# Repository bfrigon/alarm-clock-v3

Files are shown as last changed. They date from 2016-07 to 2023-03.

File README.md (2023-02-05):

alarm-clock (V3)
================

Project page [here][link-project]

Specs
-----

- Arduino based design using the ATMEGA2560 MCU.
- Plays MP3/WAV files from a SD card.
- WiFi connectivity (802.11 b/g/n)
- Automatic clock synchronization using NTP
- Send alarm state to Home Assistant via MQTT
- Large RGB seven segment display
- 16x2 character LCD display
- Night lamp
- Touch keypad
- 24h battery backup

---------------------------------------------------

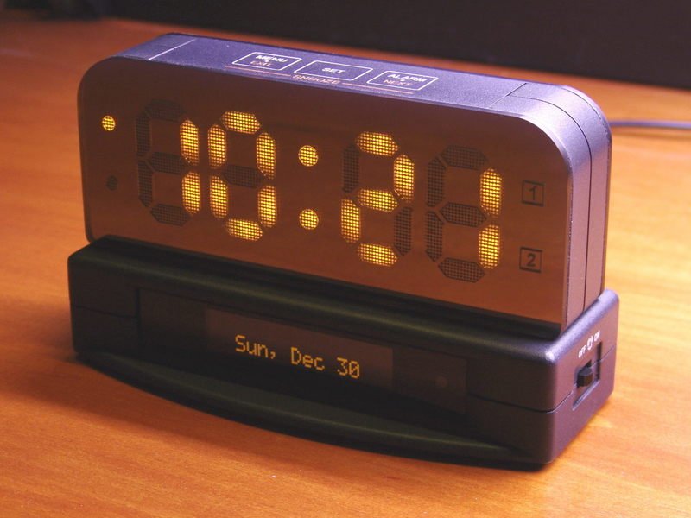
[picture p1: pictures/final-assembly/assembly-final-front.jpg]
Front view

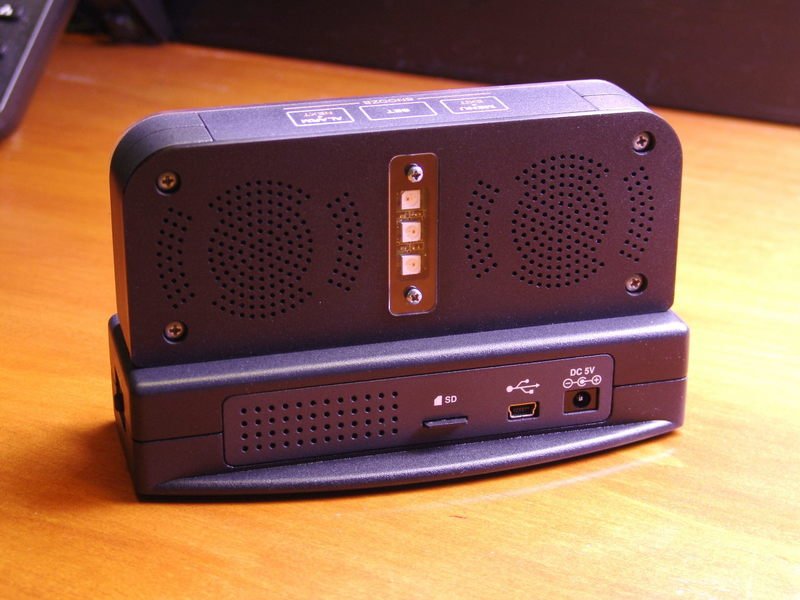
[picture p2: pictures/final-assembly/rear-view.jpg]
Rear view


Home Assistant
--------------
The clock can send the alarm switch state and next alarm timestamp to Home Assistant via MQTT. This allows to run home automations based on the alarm time. It also sends other data such as WiFi signal strength, power state, battery voltage and remaining capacity.

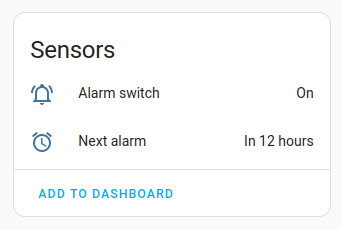
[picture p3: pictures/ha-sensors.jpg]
Home Assistant sensors


[link-project]:https://www.frigon.info/posts/projects/alarm-clock-v3/

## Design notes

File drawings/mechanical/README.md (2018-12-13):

Index
-----

Document ID   | Part #            | Description
--------------|-------------------|-------------------------------------------------
CLKV3-DWG-01  | CLKV3-PC-01       | Display - RGB digit PCB
CLKV3-DWG-02  | CLKV3-ML-01       | Display - Frame - Front
CLKV3-DWG-03  | CLKV3-ML-03       | Display - Front cover
CLKV3-DWG-04  | CLKV3-ML-09       | Display - Frame - Back
CLKV3-DWG-05  | CLKV3-ML-02       | Display - Back cover
CLKV3-DWG-06  | CLKV3-PC-02       | Display - RGB dots PCB
CLKV3-DWG-07  | CLKV3-PC-03       | Touch keypad PCB
CLKV3-DWG-08  | CLKV3-ML-04       | Touch keypad overlay
CLKV3-DWG-09  | CLKV3-PC-08       | RGB lamp PCB
CLKV3-DWG-10  | CLKV3-ML-05       | Enclosure - Lower section
CLKV3-DWG-11  | CLKV3-ML-06       | Enclosure - Upper section
CLKV3-DWG-12  | CLKV3-PC-04       | Front panel PCB
CLKV3-DWG-13  | CLKV3-ML-10       | Enclosure - Back panel
CLKV3-DWG-14  | CLKV3-PC-05       | Motherboard PCB
CLKV3-DWG-15  | CLKV3-PC-06       | Daughterboard PCB
CLKV3-DWG-16  | CLKV3-PC-07       | PSU PCB
CLKV3-DWG-17  | CLKV3-PC-09       | Alarm switch PCB
CLKV3-DWG-18  | CLKV3-ML-07       | RTC Battery door
CLKV3-DWG-19  | CLKV3-ML-08       | RGB lamp window - Frame
CLKV3-DWG-20  | CLKV3-ML-09       | RGB lamp window - Cover
CLKV3-DWG-21  | CLKV3-ML-11       | Front panel window
CLKV3-DWG-22  | CLKV3-ML-12       | Battery holder
CLKV3-DWG-30  | CLKV3-AS-01       | ASSY - Display frame - Front
CLKV3-DWG-31  | CLKV3-AS-02       | ASSY - Display frame - Back
CLKV3-DWG-32  | CLKV3-AS-03       | ASSY - Display
CLKV3-DWG-33  | CLKV3-AS-04       | ASSY - Motherboard PCB
CLKV3-DWG-34  | CLKV3-AS-05       | ASSY - Touch keypad
CLKV3-DWG-35  | CLKV3             | Final assembly
CLKV3-DWG-50  | CLKV3-JG-01       | Jig - dev.
CLKV3-DWG-51  | CLKV3-JG-02       | Motherboard assembly jig

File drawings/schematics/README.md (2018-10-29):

Index
-----

Doc ID        | Part #            | Description
--------------|-------------------|-------------------------------------------------
CLKV3-SCH-01  | CLKV3-PC-01       | Display - RGB seven seg. digit
CLKV3-SCH-02  | CLKV3-PC-02       | Display - RGB dots
CLKV3-SCH-03  | CLKV3-PC-03       | Touch keypad
CLKV3-SCH-04  | CLKV3-PC-04       | Front panel
CLKV3-SCH-05  | CLKV3-PC-05       | Motherboard
CLKV3-SCH-06  | CLKV3-PC-06       | Daughterboard
CLKV3-SCH-07  | CLKV3-PC-07       | PSU PCB
CLKV3-SCH-08  | CLKV3-PC-08       | RGB Lamp
CLKV3-SCH-09  | CLKV3-PC-09       | Alarm Swtich PCB

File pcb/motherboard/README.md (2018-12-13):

### Bill of material ###

```
Date    : 2018-10-29
Doc. ID : CLKV3-SCH-05
Project : Alarm Clock (V3)
Title   : Motherboard

Part #  : CLKV3-PC-05
REV.    : B

Components : 76
```

------------------------------------------------------------------------------------------------------------------------

| Qty | Ref. | Description | Value | Part # | Footprint |
|-----|---|---|---|---|---|
| 1 | J5 | Micro SD card connector | Micro_SD | 475710001 | conn-io:MOLEX-MICROSD-475710001 |
| 1 | J10 | Header - Dual Row - 6 Pos | PSU | BCS-103-L-D-TE | conn-header:HDR-M-2x03 |
| 1 | J6 | Header - Single Row - 4 Pos | PSU-SIG | BCS-104-L-S-TE | conn-header:HDR-M-1x04 |
| 2 | J4, J7 | Header - Dual Row - 6 Pos | ICSP | CES-103-01-T-D | conn-header:HDR-M-2x03 |
| 1 | J12 | Header - Single Row - 2 Pos | DB-C | DW-02-07-T-S-200 | conn-header:HDR-M-1x02 |
| 1 | J3 | Header - Single Row - 4 Pos | DB-B | DW-04-07-TM-S-200  | conn-header:HDR-M-1x04 |
| 1 | J9 | Header - Dual Row - 16 Pos | DB-A | DW-08-07-T-D-200 | conn-header:HDR-M-2x08 |
| 1 | J1 | DC Barrel Jack | - | PJ1-021-SMT-TR | conn-power:CUI-P1J-021-SMT |
| 1 | J2 | USB Connector - Type B | USB-MINI-B | UX60SC-MB-5ST | conn-io:USB-MB_UX60SC-MB-5ST |
| 1 | Q1 | 40V NPN small signal transistor | MMST3904 | - | smt-sot:SOT23 |
| 1 | U6 | 600mA CMOS LDO Regulator with enable | - | AP2112K-3.3 | smt-sot:SOT23-5 |
| 1 | U3 | 8-bit Atmel Microcontroller | - | ATMEGA16U2-AU | smt-qfp:QFP-7-32 |
| 1 | U1 | 8-bit Atmel Microcontroller | - | ATMEGA2560-16AU | smt-qfp:QFP-14-100 |
| 1 | U4 | IEEE 802.11 b/g/n IoT Module | - | ATWINC1500-MR210PB | misc:ATWINC1500-MR |
| 2 | U5, U7 | Hex Buffer non-inverting | - | CD74HC4050PWR | smt-sop:TSSOP16 |
| 1 | U2 | I2C Real-Time Clock | - | DS3231MZ | smt-soic:SOIC8 |
| 8 | R10, R12-R18 | Resistor | 100k | - | smt:R-0603 |
| 12  | C3, C5-C6, C9-C11, C14, C22-C26 | Capacitor | 100nF | - | smt:C-0603 |
| 9 | R1-R2, R5-R6, R9, R11, R20-R22  | Resistor | 10k | - | smt:R-0603 |
| 1 | C15 | Capacitor | 10nF | - | smt:C-0603 |
| 4 | C16-C18, C21 | Capacitor | 10uF | - | smt:C-0805 |
| 3 | R19, R23-R24 | Resistor | 1k | - | smt:R-0603 |
| 2 | R7-R8 | Resistor | 1M | - | smt:R-0603 |
| 1 | C13 | Capacitor | 1uF | - | smt:C-0603 |
| 3 | C4, C19-C20 | Capacitor | 1uF | - | smt:C-0805 |
| 4 | C1-C2, C7-C8 | Capacitor | 20pF | - | smt:C-0603 |
| 1 | C12 | Capacitor | 22pF | - | smt:C-0603 |
| 2 | R3-R4 | Resistor | 22 | - | smt:R-0603 |
| 1 | F1 | Resistor | 500mA | - | smt:R-1206 |
| 1 | DA1 | TVS Diode Array | SR05 | - | smt-sot:SOT-143 |
| 2 | D1-D2 | Diode | - | CD1206-S01575 | smt:D-1206 |
| 2 | Y1-Y2 | Crystal | 16.00 MHz  | ECS-160-20-3X-TR | crystals:smt-CSM-3X-7x4mm |
| 1 | B1 | Battery - 1 cell | CR1220 | S8411-45R | conn-power:S8411-45R |
| 1 | SW1 | Momentary SPST switch | RESET | B3F-1000 | switches:B3F-10XX |

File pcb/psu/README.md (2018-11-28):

### Bill of material ###

```
Date    : None
Doc. ID : CLKV3-SCH-07
Project : Alarm Clock (V3)
Title   : Power Supply

Part #  : CLKV3-PC-07
REV.    : A

Components : 40
```

------------------------------------------------------------------------------------------------------------------------

| Qty | Ref. | Description | Value | Part # | Footprint |
|-----|---|---|---|---|---|
| 1 | J3 | Header - Single Row - 2 Pos | BATTERY  | S2B-PH-K-S | conn-jst:S2B-PH-K |
| 1 | J1 | Header - Dual Row - 6 Pos | VIN | TSW-103-07-F-D | conn-header:HDR-M-2x03  |
| 1 | J2 | Header - Single Row - 4 Pos | SIGNAL | TSW-104-07-F-S | conn-header:HDR-M-1x04  |
| 2 | Q1-Q2 | 40V NPN small signal transistor | MMST3904 | - | smt-sot:SOT23 |
| 1 | U2 | Li-Ion Battery charger and Power-Path management | - | BQ24075 | smt-qfn:QFN16-EP-3x3 |
| 1 | U1 | System-side Impedance Track Fuel Gauge | - | BQ27441-G1 | smt-son:PDSO-N12 |
| 1 | U3 | 2V to 16V Buck-Boost converter | - | TPS630701 | smt-qfn:VQFN15N |
| 1 | R2 | Resistor | 0.01 1%  | - | smt:R-1206 |
| 1 | R10 | Resistor | 0 | - | smt:R-0603 |
| 1 | R9 | Resistor | 1.1k | - | smt:R-0603 |
| 5 | R3-R6, R12 | Resistor | 100k | - | smt:R-0603 |
| 1 | C4 | Capacitor | 100nF | - | smt:C-0603 |
| 6 | R1, R11, R13-R16 | Resistor | 10k | - | smt:R-0603 |
| 2 | C3, C5 | Capacitor | 10uF | - | smt:C-0603 |
| 5 | C1-C2, C11-C13 | Capacitor | 10uF | - | smt:C-0805 |
| 1 | C10 | Capacitor | 1uF | - | smt:C-0603 |
| 3 | C6-C8 | Capacitor | 22uF | - | smt:C-0805 |
| 1 | C9 | Capacitor | 470nF | - | smt:C-0603 |
| 1 | R8 | Resistor | 5.6k | - | smt:R-0603 |
| 1 | R17 | Resistor | 680 | - | smt:R-0603 |
| 1 | R7 | Resistor | 787k | - | smt:R-0603 |
| 1 | D1 | Led | RED | 150080RS75000 | smt:LED-0805 |
| 1 | L1 | Inductor | 1.5uH | SPM5030T-1R5M-HZ | smt-inductor:SPM5030-HZ |

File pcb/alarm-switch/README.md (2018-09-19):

### Bill of material ###

```
Date    : 2018-08-14
Doc. ID : CLKV3-SCH-09
Project : Alarm Clock V3
Title   : Alarm Switch Pcb

Part #  : CLKV3-PC-09
REV.    : A

Components : 1
```

------------------------------------------------------------------------------------------------------------------------

| Qty | Ref. | Description | Value | Part # | Footprint |
|-----|---|---|---|---|---|
| 1 | SW1  | Momentary SPST switch | L102011ML04Q | - | switches:CK_L102XXXML04 |

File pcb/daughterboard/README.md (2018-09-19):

### Bill of material ###

```
Date    : 2018-09-19
Doc. ID : CLKV3-SCH-06
Project : Alarm Clock (V3)
Title   : Daughterboard

Part #  : CLKV3-PC-06
REV.    : A

Components : 70
```

------------------------------------------------------------------------------------------------------------------------

| Qty | Ref. | Description | Value | Part # | Footprint |
|-----|---|---|---|---|---|
| 1 | J7 | Header - Single Row - 2 Pos | ALARM SW | DF3A-2P-2DSA | conn-header:DF3A-2P-2DSA  |
| 1 | J1 | Header - Single Row - 3 Pos | LAMP | DF3A-3P-2DSA | conn-header:DF3A-3P-2DSA  |
| 1 | J3 | Header - Single Row - 4 Pos | SPKR | DF3A-4P-2DSA | conn-header:DF3A-4P-2DSA  |
| 1 | J2 | Header - Single Row - 8 Pos | DISPLAY | DF3A-8P-2DSA | conn-header:DF3A-8P-2DSA  |
| 1 | U2 | Single inverter | - | 74AHC1G04SE-7 | smt-sot:SOT-353 |
| 1 | U3 | Dual 150mA LDO Regulator | - | AP7312-1833W6 | smt-sot:SOT23-6 |
| 1 | Q1 | Single P-Channel MOSFET 20V 10A | NTF6P02 | NTF6P02T3G | smt-sot:SOT-223 |
| 1 | U5 | Dual non-inverting buffer | - | SN74LVC2G34DBV | smt-sot:SOT23-6 |
| 1 | U4 | 2.8W/Ch Stereo Class-D Audio Amplifier | - | TPA2016D2 | smt-qfn:QFN20-EP-4x4 |
| 1 | U1 | MP3/AAC/MIDI Audio Codec | - | VS1053B | smt-qfp:QFP-7-48 |
| 10  | R4, R6, R12-R19 | Resistor | 100k | - | smt:R-0603 |
| 14  | C1-C10, C26-C27, C29-C30 | Capacitor | 100nF | - | smt:C-0603 |
| 3 | R2, R7, R11 | Resistor | 10k | - | smt:R-0603 |
| 2 | C18-C19 | Capacitor | 10nF | - | smt:C-0603 |
| 1 | R8 | Resistor | 10 | - | smt:R-0603 |
| 3 | C11, C14, C16 | Electrolytic capacitor | 10uF 6V3 | - | smt:CPL-0805 |
| 3 | C24-C25, C28 | Capacitor | 10uF | - | smt:C-0805 |
| 1 | R5 | Resistor | 1M | - | smt:R-0603 |
| 4 | C31-C34 | Capacitor | 1nF | - | smt:C-0603 |
| 5 | C15, C20-C23 | Capacitor | 1uF | - | smt:C-0805 |
| 2 | C12-C13 | Capacitor | 20pF | - | smt:C-0603 |
| 2 | R9-R10 | Resistor | 20 | - | smt:R-0603 |
| 2 | R1, R3 | Resistor | 470 | - | smt:R-0603 |
| 1 | C17 | Capacitor | 47nF | - | smt:C-0603 |
| 2 | L1-L2 | Ferrite | - | 2508053007Y0 | smt:FER-0805 |
| 1 | Y1 | Crystal | 12.288 MHz | ECS-122.8-20-3X-EN-TR | crystals:smt-CSM-3X-7x4mm |
| 4 | L3-L6 | Ferrite | - | MPZ1608S221A | smt:FER-0603 |

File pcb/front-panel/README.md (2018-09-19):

### Bill of material ###

```
Date    : 2018-08-22
Doc. ID : CLKV3-SCH-04
Project : Alarm Clock (V3)
Title   : Front Panel

Part #  : CLKV3-PC-04
REV.    : B

Components : 23
```

------------------------------------------------------------------------------------------------------------------------

| Qty | Ref. | Description | Value | Part # | Footprint |
|-----|---|---|---|---|---|
| 2 | Q1-Q2 | N-Channel MOSFET | - | BSS138 | smt-sot:SOT23 |
| 1 | U4 | 100 mA LDO Regulator w/ Shutdown | - | LP2981-33DBVT  | smt-sot:SOT23-5 |
| 1 | U2 | DC/DC Converter | - | LT1109CS8-12 | smt-soic:SOIC8 |
| 1 | U3 | Light To Digital Converter (I2C) | - | TSL2591 | smt-dfn:DFN6 |
| 1 | U1 | 16x2 character OLED display | - | ER-OLED1602-4W | misc:LCD-ER-OLED1602 |
| 3 | C3, C6, C8 | Capacitor | 100nF | - | smt:C-0603 |
| 2 | R2-R3 | Resistor | 10k | - | smt:R-0603 |
| 1 | C4 | Electrolytic capacitor | 10uF  | - | smt:CPL-0805 |
| 2 | C1, C9 | Capacitor | 1uF | - | smt:C-0805 |
| 1 | C7 | Electrolytic capacitor | 22uF  | - | smt:CPL-2312 |
| 1 | C10 | Capacitor | 3.3uF | - | smt:C-0805 |
| 2 | R4-R5 | Resistor | 4.7k  | - | smt:R-0603 |
| 1 | C5 | Electrolytic capacitor | 4.7uF | - | smt:CPL-0805 |
| 1 | C2 | Electrolytic capacitor | 4.7uF | - | smt:CPL-1206 |
| 1 | R1 | Resistor | 500k  | - | smt:R-0603 |
| 1 | L1 | Inductor | 33uH  | CR54NP-330LC | smt:IND-CD54 |
| 1 | D1 | Schottky Diode | - | MBRS120T3 | smt:DO-214-AA |

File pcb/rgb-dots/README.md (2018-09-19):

### Bill of material ###

```
Date    : 2018-08-29
Doc. ID : CLKV3-SCH-02
Project : Alarm Clock (V3)
Title   : Display - Rgb Dots

Part #  : CLKV3-PC-02
REV.    : B

Components : 4
```

------------------------------------------------------------------------------------------------------------------------

| Qty | Ref.  | Description | Value | Part # | Footprint |
|-----|---|---|---|---|---|
| 2 | U1-U2 | Digital 5050 RGB LED | - | IN-PI554FCH | SMT:LED-5050 |
| 2 | C1-C2 | Capacitor | 100nF | - | SMT-0603 |

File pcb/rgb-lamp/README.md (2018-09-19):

### Bill of material ###

```
Date    : 2018-09-19
Doc. ID : CLKV3-SCH-08
Project : Alarm Clock (V3)
Title   : Rgb Lamp

Part #  : CLKV3-PC-08
REV.    : B

Components : 6
```

------------------------------------------------------------------------------------------------------------------------

| Qty | Ref.  | Description | Value | Part # | Footprint |
|-----|---|---|---|---|---|
| 3 | U1-U3 | Digital 5050 RGB LED | - | IN-PI554FCH | smt:LED-5050 |
| 3 | C1-C3 | Capacitor | 100nF | - | smt:C-0603 |

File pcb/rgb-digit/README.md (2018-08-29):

### Bill of material ###

```
Date    : 2018-08-29
Doc. ID : CLKV3-SCH-01
Project : Alarm Clock (V3)
Title   : Display - Rgb Seven Seg. Digit

Part #  : CLKV3-PC-01
REV.    : A

Components : 16
```

------------------------------------------------------------------------------------------------------------------------

| Qty | Ref.  | Description | Value | Part # | Footprint |
|-----|---|---|---|---|---|
| 7 | U1-U7 | Digital 5050 RGB LED | - | IN-PI554FCH | SMT:LED-5050 |
| 7 | C1-C7 | Capacitor | 100nF | - | SMT-0603 |
| 1 | C9 | Electrolytic capacitor | 10uF  | - | SMT-1206 |
| 1 | C8 | Electrolytic capacitor | 1uF | - | SMT-1206 |

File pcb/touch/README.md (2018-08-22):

### Bill of material ###

```
Date    : 2018-07-05
Doc. ID : CLKV3-SCH-03
Project : Alarm Clock (V3)
Title   : Touch Keypad

Part #  : CLKV3-PC-03
REV.    : B

Components : 16
```

------------------------------------------------------------------------------------------------------------------------

| Qty | Ref. | Description | Value | Part # | Footprint |
|-----|---|---|---|---|---|
| 1 | U1 | 7 channel QTouch Touch sensor IC | - | AT42QT1070 | smt-soic:SOIC14N |
| 2 | Q1-Q2 | N-Channel MOSFET | - | BSS138 | smt-sot:SOT23 |
| 1 | U2 | 100 mA LDO Regulator w/ Shutdown | - | LP2981-33DBVT | smt-sot:SOT23-5  |
| 1 | R2 | Resistor | 100k  | - | smt:R-0603 |
| 1 | C2 | Capacitor | 100nF | - | smt:C-0603 |
| 4 | R1, R3, R7-R8 | Resistor | 10k | - | smt:R-0603 |
| 2 | C1, C3 | Capacitor | 1uF | - | smt:C-0805 |
| 1 | C4 | Capacitor | 3.3uF | - | smt:C-0805 |
| 3 | R4-R6 | Resistor | 470 | - | smt:R-0603 |

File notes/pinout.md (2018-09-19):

Motherboard pinout
==================

J1 : DC Jack
------------

Pin | Name
----|------------------------
1   | VIN
2   | GND
3   | GND

J10 : PSU board
---------------

Pin | Name    | Pin | Name
----|---------|-----|---------------------------
1   | VIN     | 2   | VIN
3   | +5V     | 4   | +5V
5   | GND     | 6   | GND

J3 : PSU status
-------------------------

Pin | Name
----|------------------------
1   | Low battery signal
2   | On battery

J9 : Daughter board (DB-A)
-----------------------

Pin | Name                    | Pin | Name
----|-------------------------|-----|---------------------------
1   | +5V                     | 2   | +5V
3   | GND                     | 4   | GND
5   | RGB pixels data (clock) | 6   | RGB pixels data (lamp)
7   | CCS (3.3v)              | 8   | RGB pixels shutdonw
9   | Codec reset (3.3v)      | 10  | DREQ
11  | MOSI (3.3v)             | 12  | SCLK (3.3v)
13  | MISO                    | 14  | XDCS (3.3v)
15  | DVDD (3.3v LDO)         | 16  | Alarm switch

J3 : Daughter board (DB-B)
-------------------------

Pin | Name
----|------------------------
1   | SDA
2   | SCL
3   | Amplifier shutdown
4   | Keypad INT

J8 : Front panel
----------------

Pin | Name
----|------------------------
1   | +5V
2   | SDA
3   | SCL
4   | OLED reset
5   | ALS interrupt
6   | GND

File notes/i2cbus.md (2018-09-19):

### I2C Bus address list ###

Address | Device               | Part #
--------|----------------------|-------------------
0xD0    | RTC                  | DS3231MZ
0xB0    | Audio amplifier      | TPA2016D2
0x1B    | Touch sensor IC      | AT42QT1070
0x78    | OLED display         | ER-OLED1602-4W
0x29    | Ambient light sensor | TSL2591

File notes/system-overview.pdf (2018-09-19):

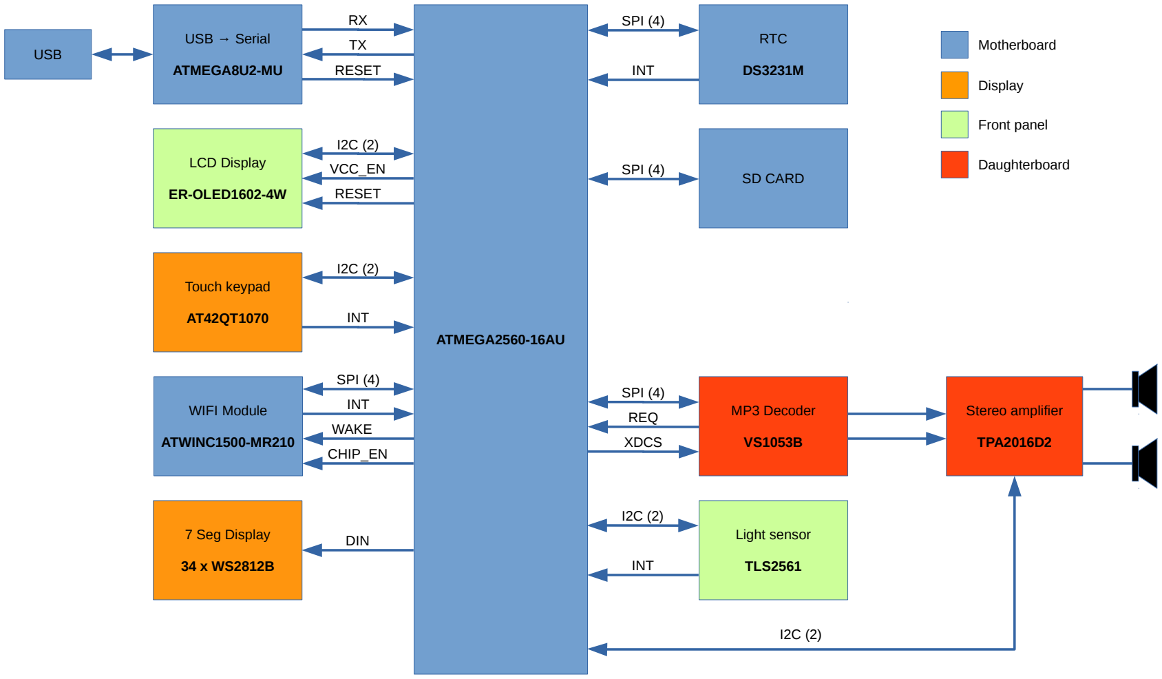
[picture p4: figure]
ATMEGA2560-16AU; USB; RTC; SD CARD; MP3 Decoder; SPI (4); INT; Stereo amplifier; TPA2016D2; REQ; XDCS; USB → Serial; ATMEGA8U2-MU; LCD Display; ER-OLED1602-4W; Touch keypad; WIFI Module; ATWINC1500-MR210; WAKE; CHIP_EN; Light sensor; TLS2561; 7 Seg Display; DIN; RESET; VCC_EN; Motherboard; Display; Front panel; Daughterboard

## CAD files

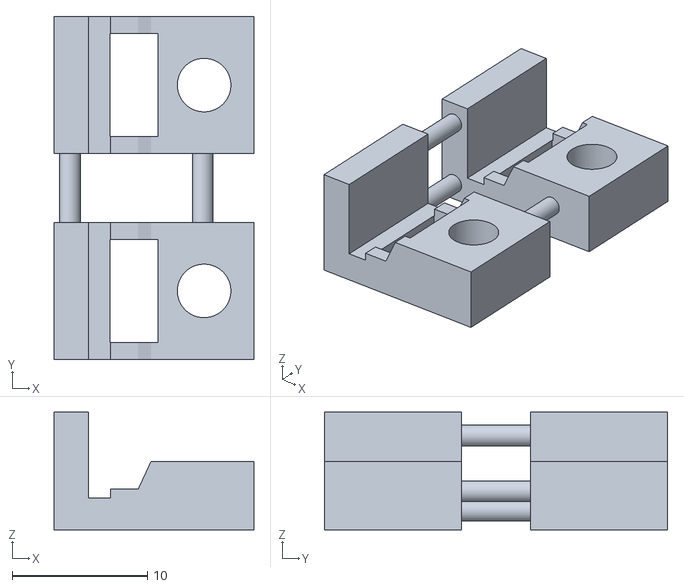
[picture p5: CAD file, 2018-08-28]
fab-files/stl-files/jig-assy-motherboard.stl
14.8 x 25.4 x 8.74

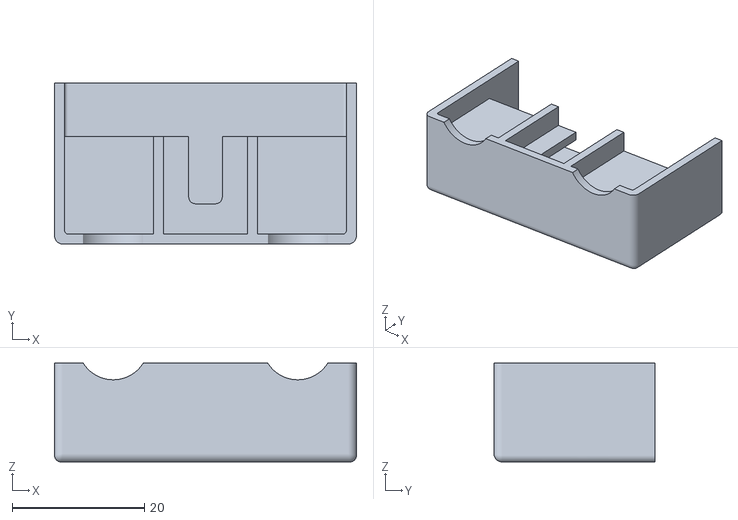
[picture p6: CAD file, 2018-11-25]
fab-files/stl-files/battery-holder.stl
45.7 x 24.4 x 15.0

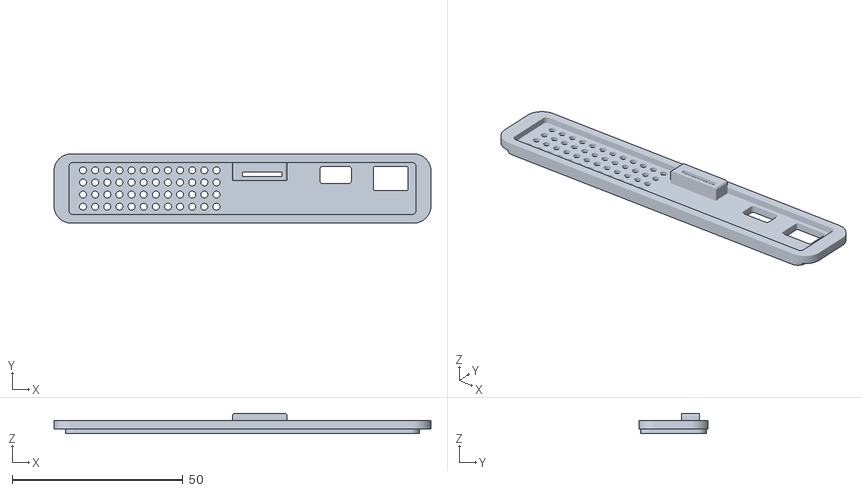
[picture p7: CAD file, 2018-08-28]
fab-files/stl-files/back panel.stl
110.5 x 20.3 x 5.97

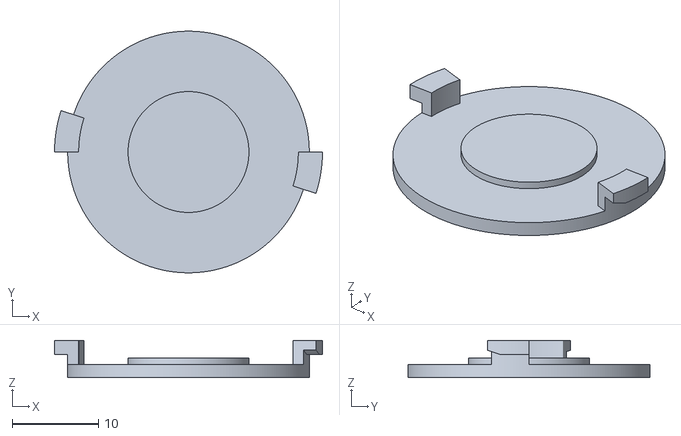
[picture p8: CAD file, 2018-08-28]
fab-files/stl-files/battery-door.stl
31.0 x 27.9 x 4.32

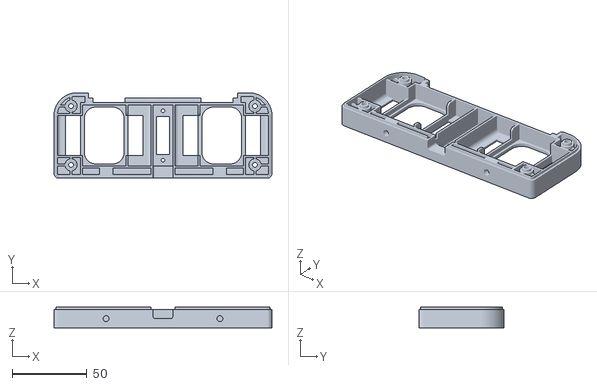
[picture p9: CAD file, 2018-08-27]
fab-files/stl-files/display-frame-back.stl
146.1 x 57.1 x 14.0

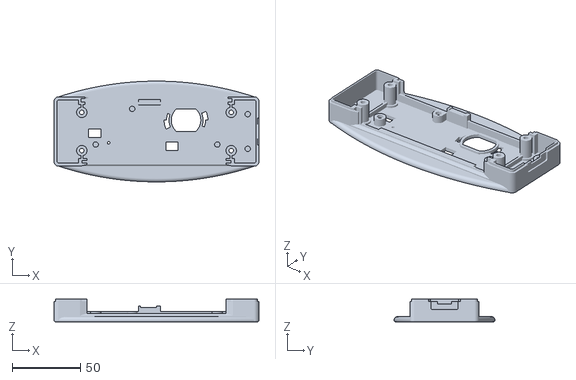
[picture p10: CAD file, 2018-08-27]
fab-files/stl-files/base - lower section.stl
149.9 x 73.7 x 16.5

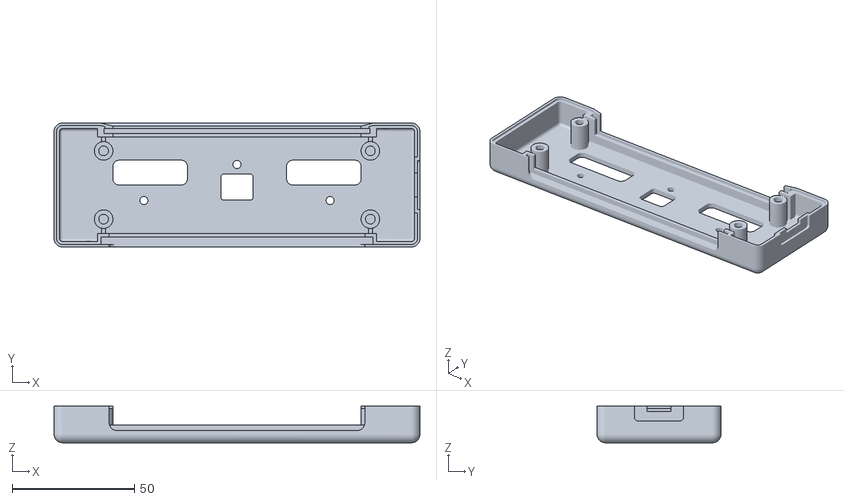
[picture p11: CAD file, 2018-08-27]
fab-files/stl-files/base-upper-section.stl
149.9 x 50.8 x 15.0

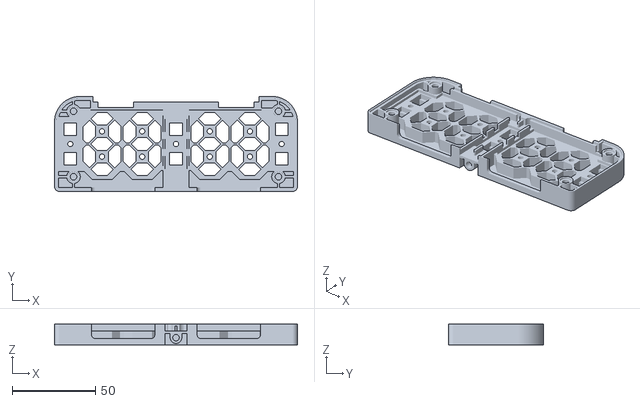
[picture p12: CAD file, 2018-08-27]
fab-files/stl-files/display-frame-front.stl
146.1 x 57.1 x 12.4

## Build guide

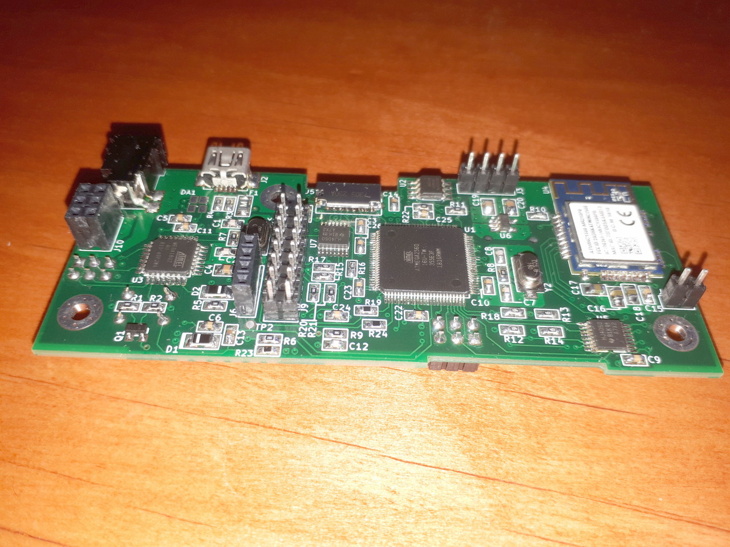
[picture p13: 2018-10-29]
pictures/motherboard/Motherboard-assembled-top.jpg

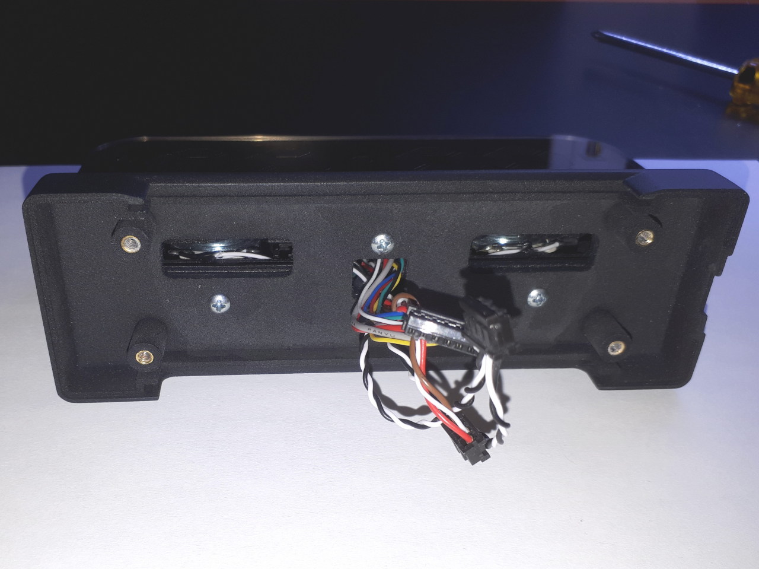
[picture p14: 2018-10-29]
pictures/final-assembly/assembly-enclosure-top.jpg

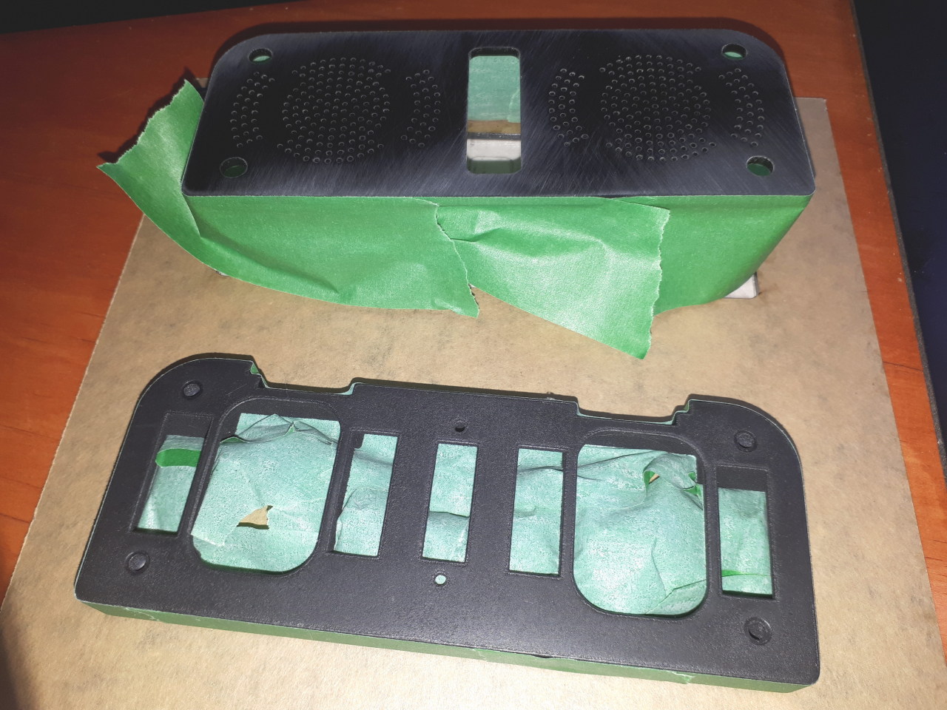
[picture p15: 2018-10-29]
pictures/display-panel/frame-back-cover-assembly-masking.jpg

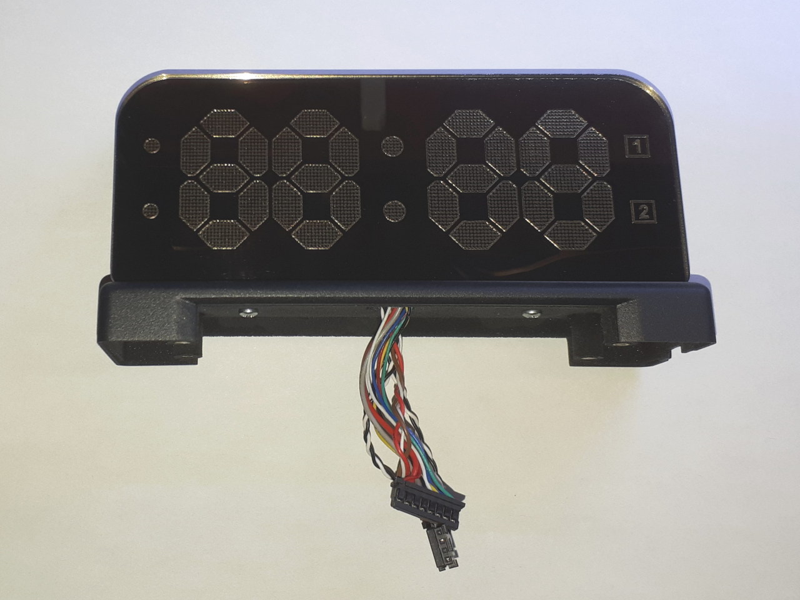
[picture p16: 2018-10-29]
pictures/final-assembly/assembly-display-panel-installed.jpg

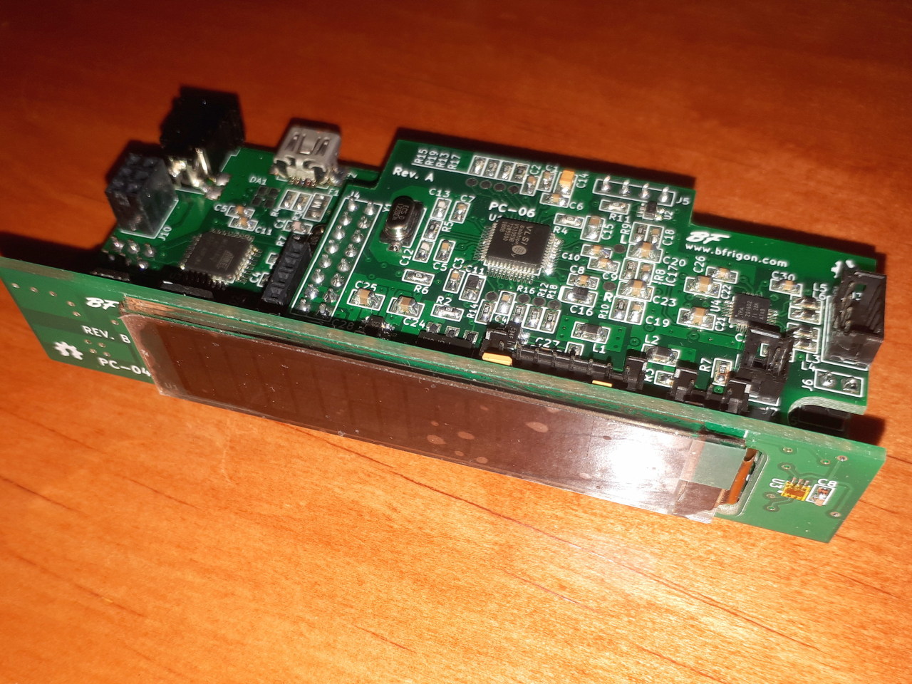
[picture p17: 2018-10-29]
pictures/motherboard/motherboard-final-assembly-front.jpg

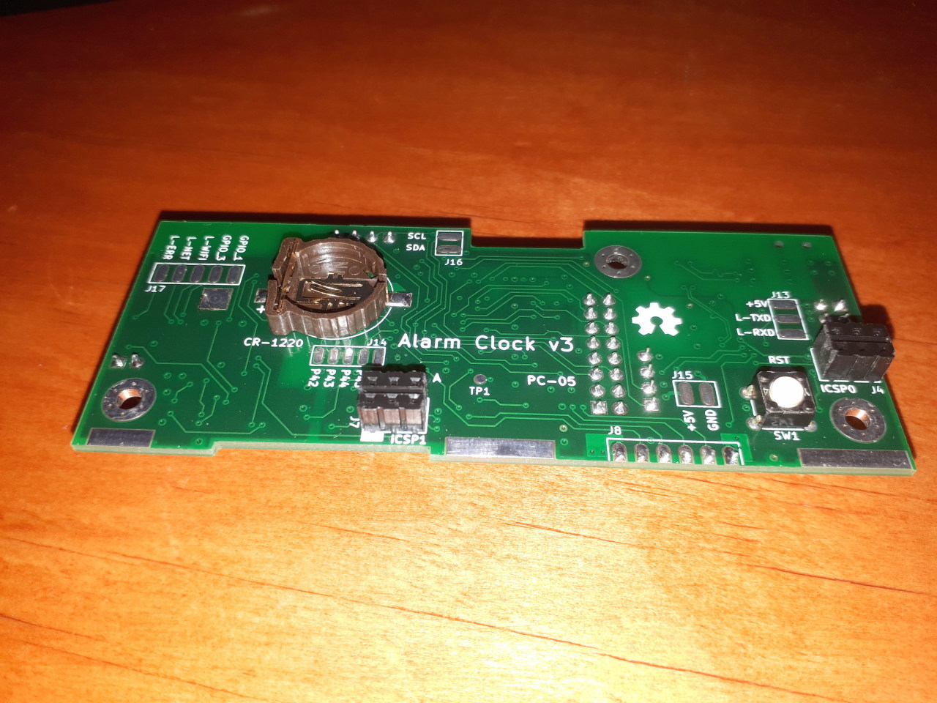
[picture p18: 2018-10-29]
pictures/motherboard/motherboard-assembled-bottom.jpg

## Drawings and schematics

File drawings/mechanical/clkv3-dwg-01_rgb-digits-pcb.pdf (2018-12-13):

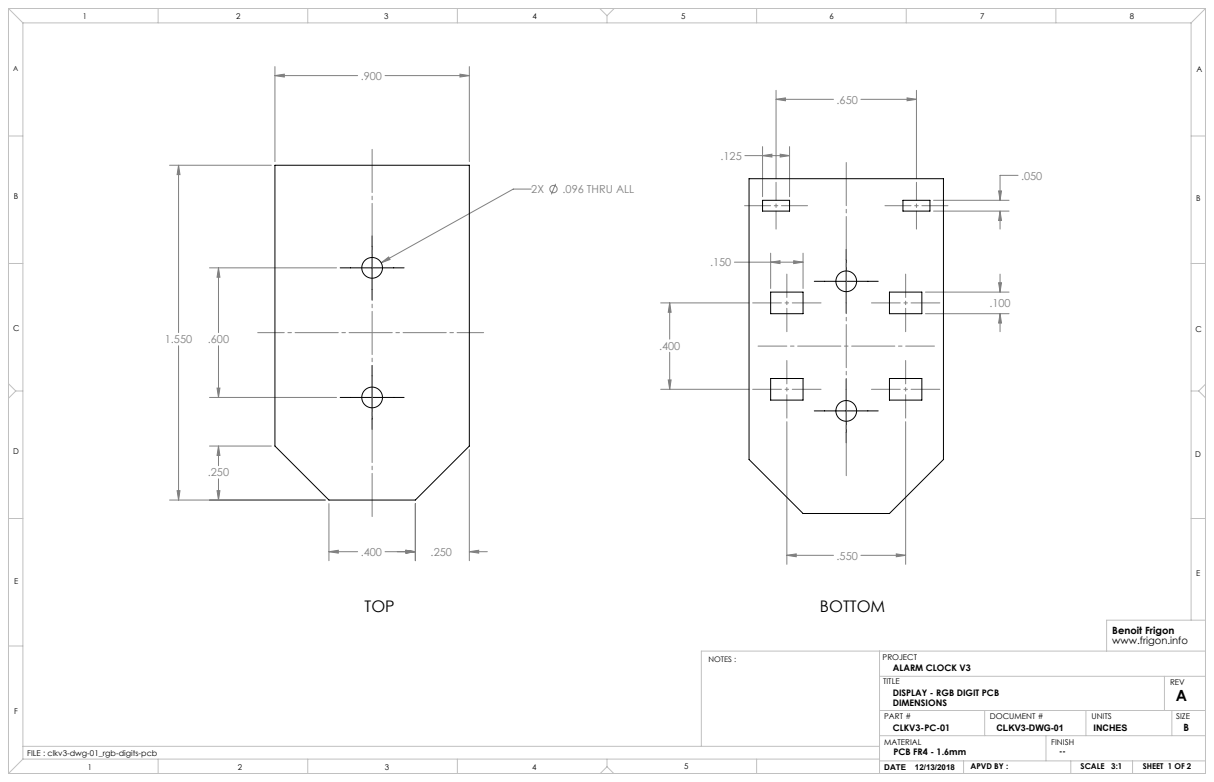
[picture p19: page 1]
.096 THRU ALL; SHEET 1 OF 2; ALARM CLOCK V3; DISPLAY - RGB DIGIT PCB; PART #; DOCUMENT #; UNITS; DATE 12/13/2018; SCALE 3:1; PCB FR4 - 1.6mm; NOTES :; APVD BY :

Benoit Frigon
www.frigon.info

FILE : clkv3-dwg-01_rgb-digits-pcb

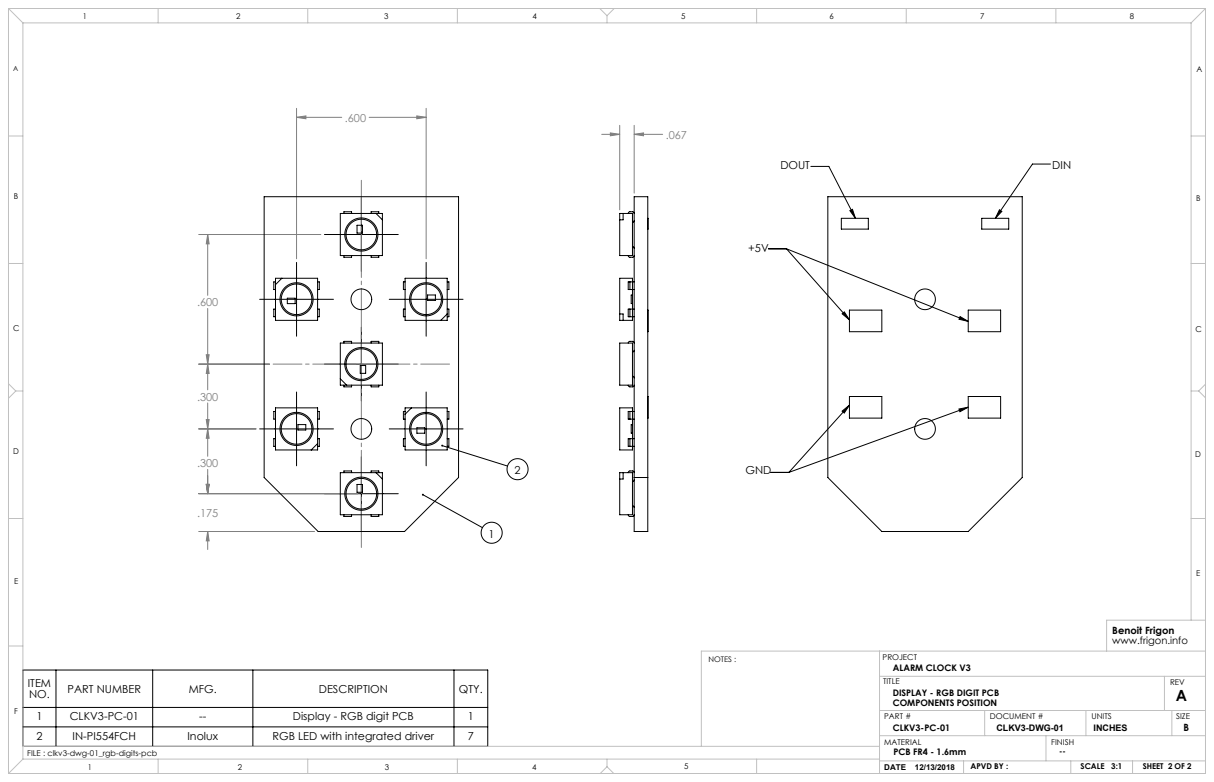
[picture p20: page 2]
SHEET 2 OF 2; DOCUMENT #; UNITS; SCALE 3:1; NOTES :; APVD BY :

Benoit Frigon
www.frigon.info

PROJECT
ALARM CLOCK V3
TITLE
DISPLAY - RGB DIGIT PCB
COMPONENTS POSITION
PART #
CLKV3-PC-01
MATERIAL
PCB FR4 - 1.6mm
DATE 12/13/2018

ITEM NO. | PART NUMBER | MFG. | DESCRIPTION | QTY.

1 | CLKV3-PC-01 | -- | Display - RGB digit PCB | 1
2 | IN-PI554FCH | Inolux | RGB LED with integrated driver | 7

FILE : clkv3-dwg-01_rgb-digits-pcb

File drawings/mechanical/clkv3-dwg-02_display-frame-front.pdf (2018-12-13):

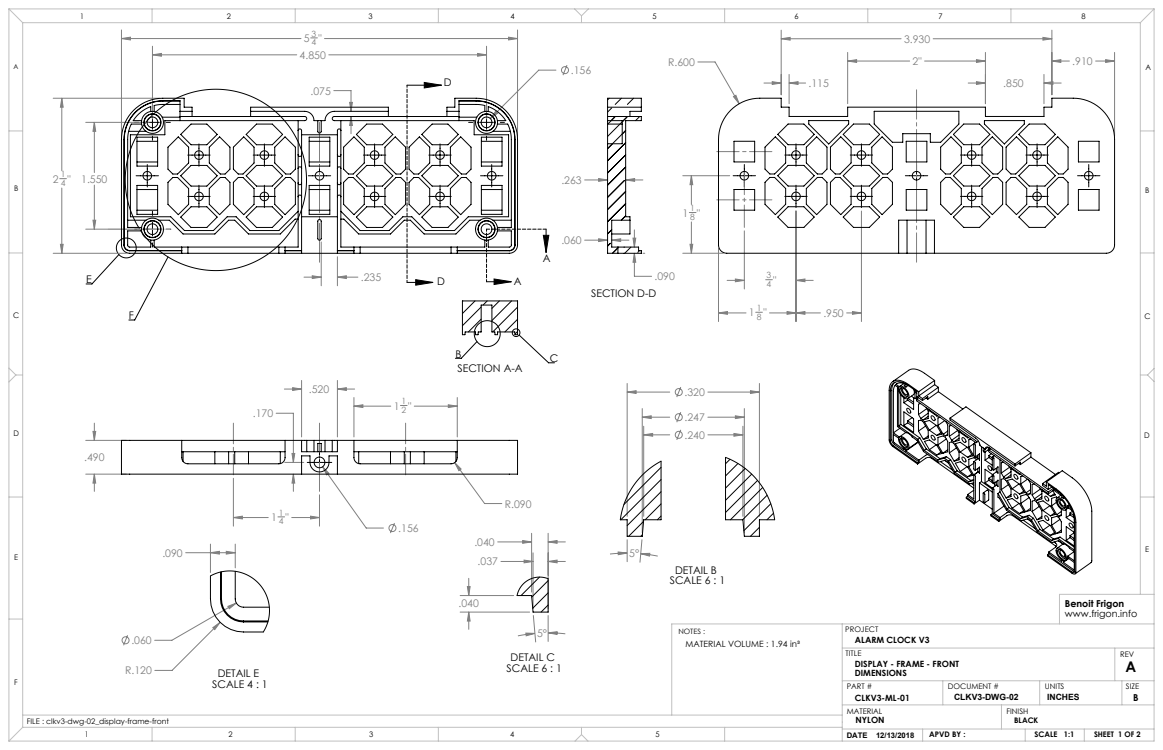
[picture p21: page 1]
SECTION A-A; DETAIL B SCALE 6 : 1; SECTION D-D; DETAIL C SCALE 6 : 1; DETAIL E SCALE 4 : 1; SHEET 1 OF 2; ALARM CLOCK V3; DISPLAY - FRAME - FRONT; PART #; DOCUMENT #; UNITS; DATE 12/13/2018; SCALE 1:1; APVD BY :

Benoit Frigon
www.frigon.info

NOTES :
MATERIAL VOLUME : 1.94 in³

FILE : clkv3-dwg-02_display-frame-front

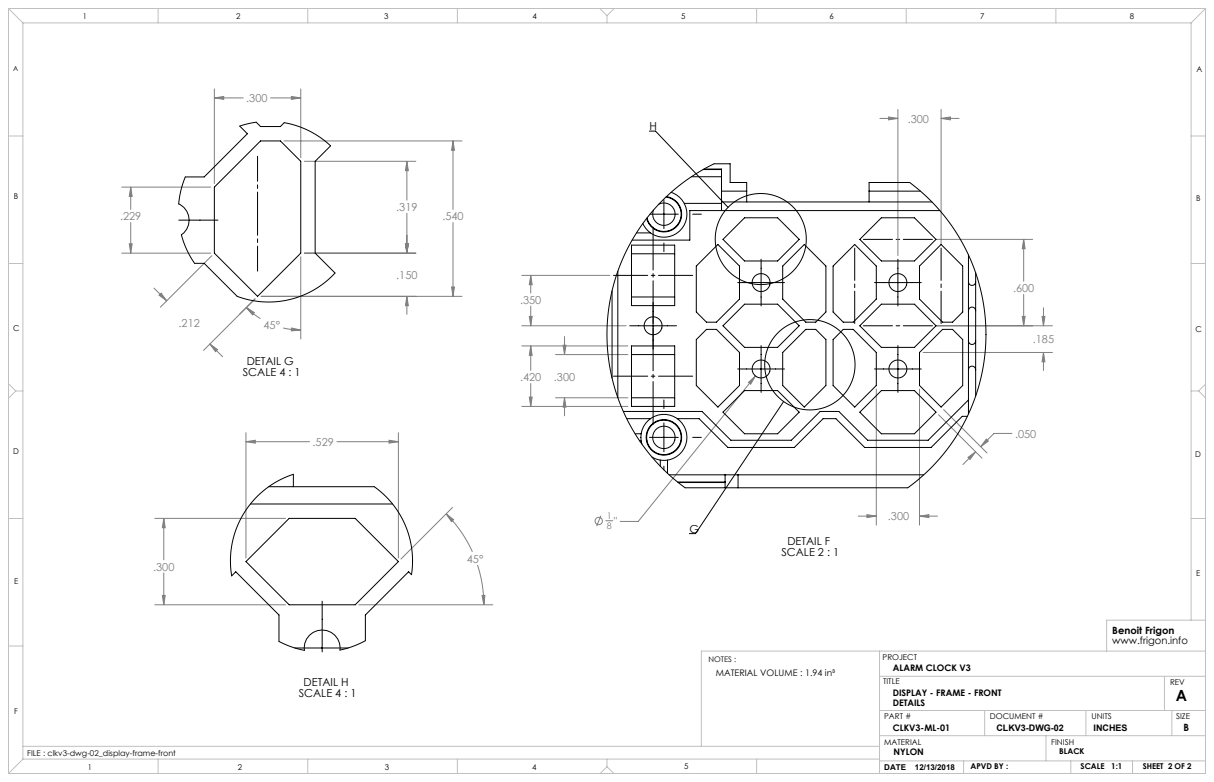
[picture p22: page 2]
DETAIL F SCALE 2 : 1; DETAIL G SCALE 4 : 1; DETAIL H SCALE 4 : 1; SHEET 2 OF 2; ALARM CLOCK V3; DISPLAY - FRAME - FRONT; PART #; DOCUMENT #; UNITS; DATE 12/13/2018; SCALE 1:1; APVD BY :

Benoit Frigon
www.frigon.info

NOTES :
MATERIAL VOLUME : 1.94 in³

FILE : clkv3-dwg-02_display-frame-front

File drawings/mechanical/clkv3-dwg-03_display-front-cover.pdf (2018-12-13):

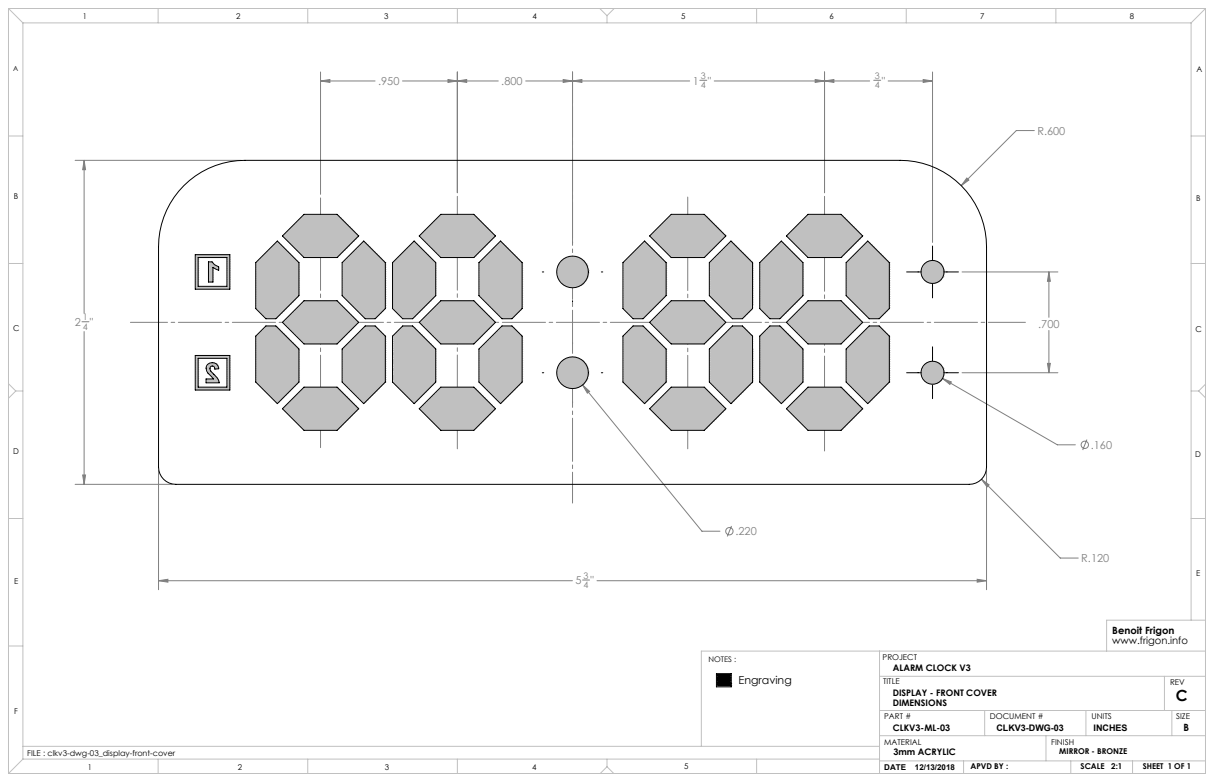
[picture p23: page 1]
SHEET 1 OF 1; ALARM CLOCK V3; DISPLAY - FRONT COVER; PART #; DOCUMENT #; UNITS; DATE 12/13/2018; SCALE 2:1; 3mm ACRYLIC; MIRROR - BRONZE; NOTES :; APVD BY :

Benoit Frigon
www.frigon.info

FILE : clkv3-dwg-03_display-front-cover

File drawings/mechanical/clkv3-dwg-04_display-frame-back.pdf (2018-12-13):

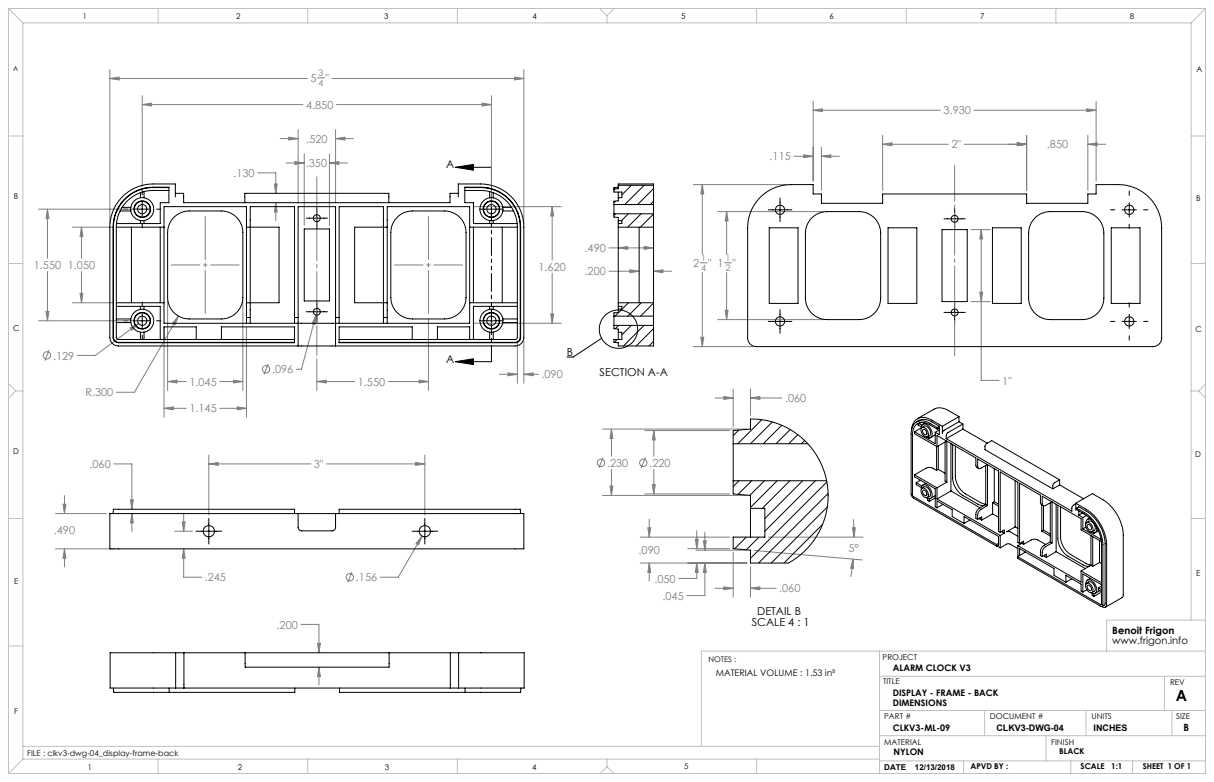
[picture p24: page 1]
SECTION A-A; DETAIL B; SCALE 4 : 1; SHEET 1 OF 1; ALARM CLOCK V3; DISPLAY - FRAME - BACK; PART #; DOCUMENT #; UNITS; DATE 12/13/2018; SCALE 1:1; APVD BY :

Benoit Frigon
www.frigon.info

NOTES :
MATERIAL VOLUME : 1.53 in³

FILE : clkv3-dwg-04_display-frame-back

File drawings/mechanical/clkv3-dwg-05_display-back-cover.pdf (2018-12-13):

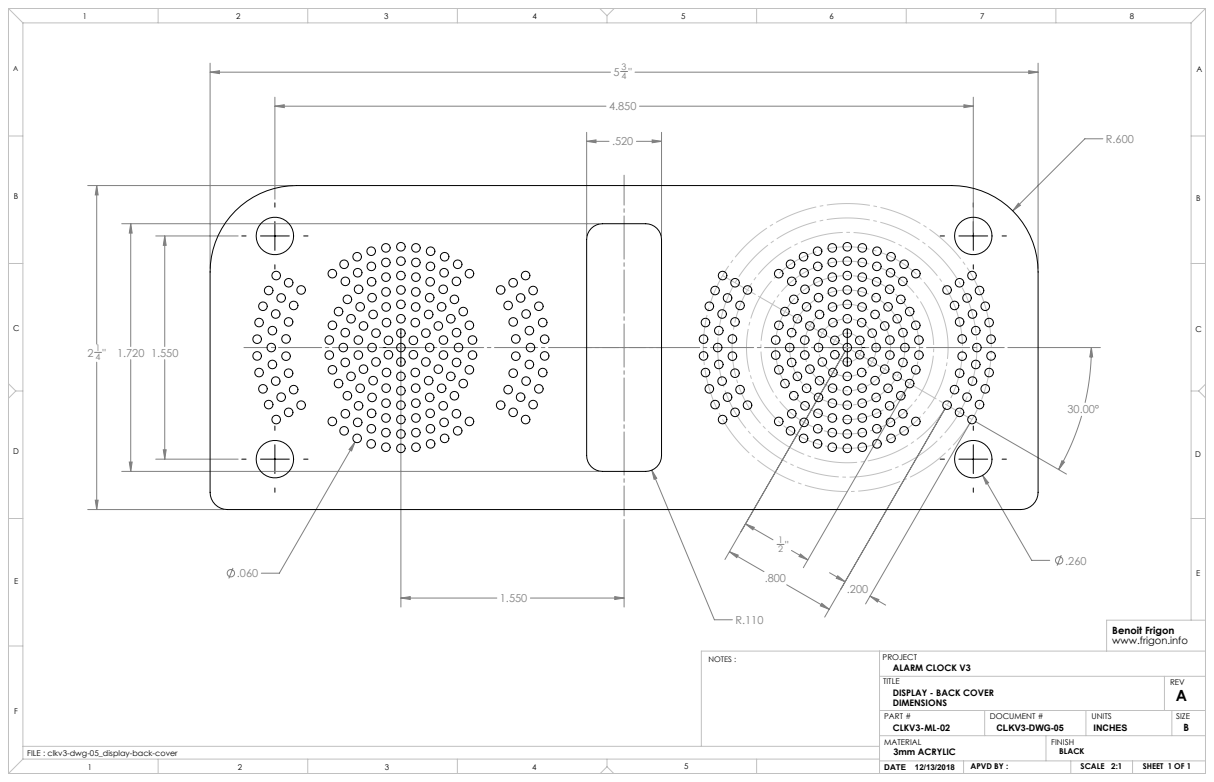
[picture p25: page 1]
SHEET 1 OF 1; ALARM CLOCK V3; DISPLAY - BACK COVER; PART #; DOCUMENT #; UNITS; DATE 12/13/2018; SCALE 2:1; 3mm ACRYLIC; NOTES :; APVD BY :

Benoit Frigon
www.frigon.info

FILE : clkv3-dwg-05_display-back-cover

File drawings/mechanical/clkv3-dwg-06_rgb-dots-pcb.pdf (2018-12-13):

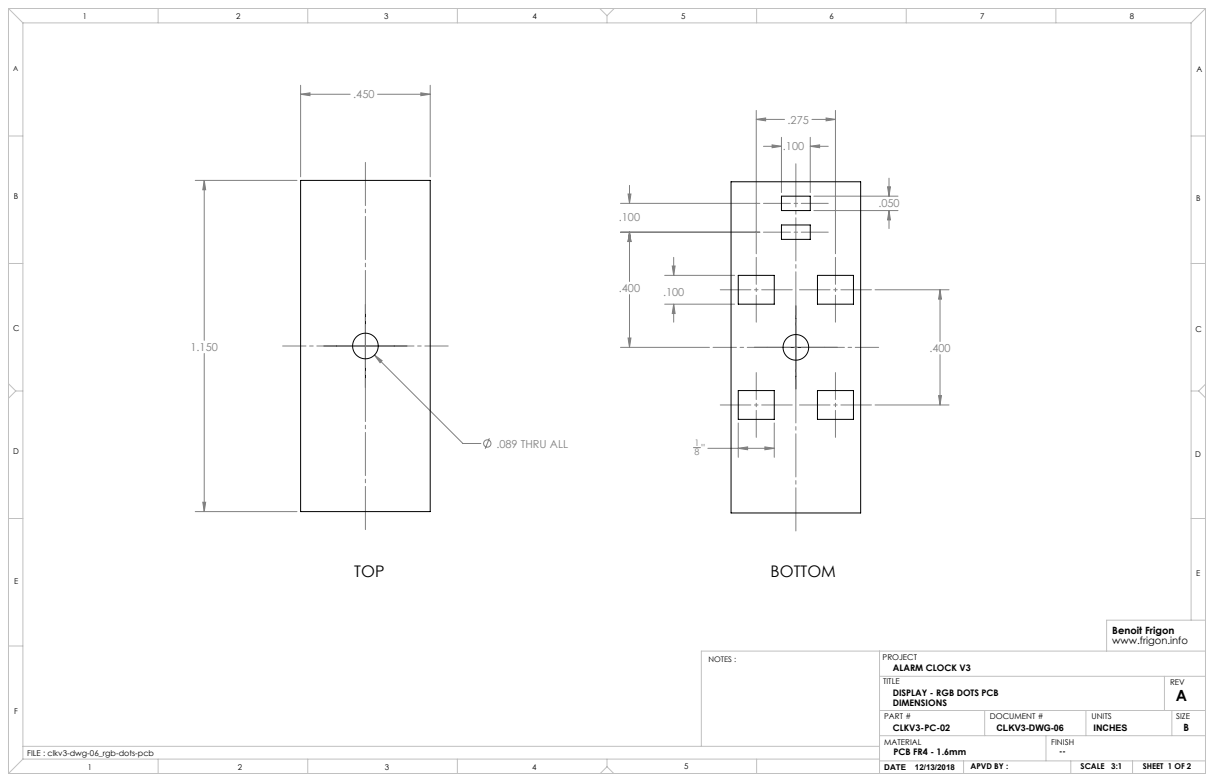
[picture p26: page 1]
.089 THRU ALL; SHEET 1 OF 2; ALARM CLOCK V3; DISPLAY - RGB DOTS PCB; PART #; DOCUMENT #; UNITS; DATE 12/13/2018; SCALE 3:1; PCB FR4 - 1.6mm; NOTES :; APVD BY :

Benoit Frigon
www.frigon.info

FILE : clkv3-dwg-06_rgb-dots-pcb

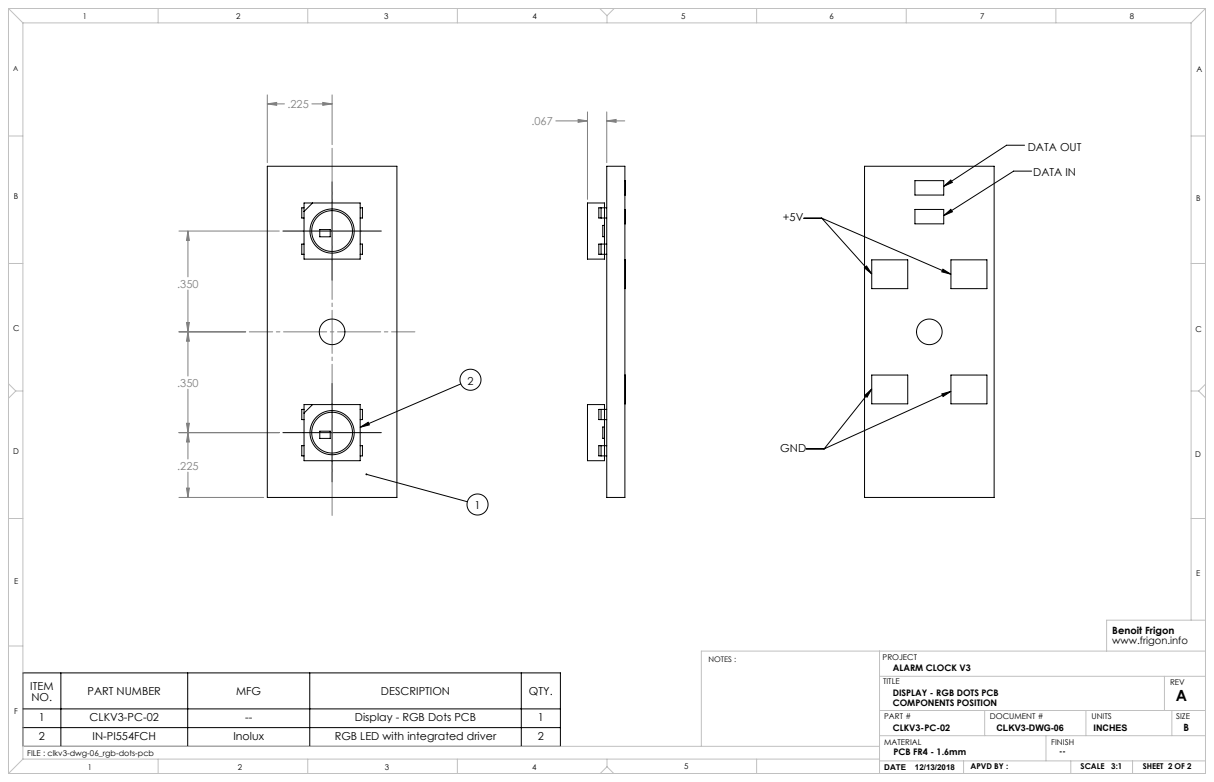
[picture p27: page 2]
DATA OUT; DATA IN; SHEET 2 OF 2; DOCUMENT #; UNITS; SCALE 3:1; NOTES :; APVD BY :

Benoit Frigon
www.frigon.info

PROJECT
ALARM CLOCK V3
TITLE
DISPLAY - RGB DOTS PCB
COMPONENTS POSITION
PART #
CLKV3-PC-02
MATERIAL
PCB FR4 - 1.6mm
DATE 12/13/2018

ITEM NO. | PART NUMBER | MFG | DESCRIPTION | QTY.

1 | CLKV3-PC-02 | -- | Display - RGB Dots PCB | 1
2 | IN-PI554FCH | Inolux | RGB LED with integrated driver | 2

FILE : clkv3-dwg-06_rgb-dots-pcb

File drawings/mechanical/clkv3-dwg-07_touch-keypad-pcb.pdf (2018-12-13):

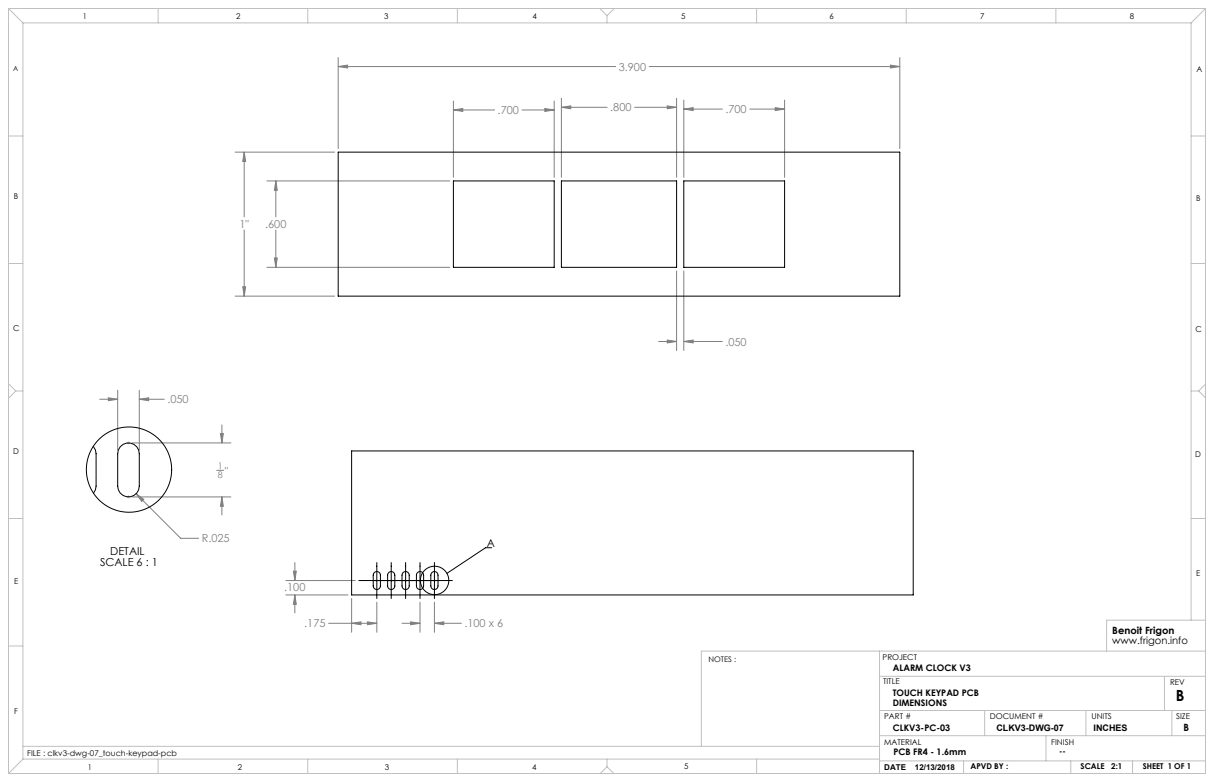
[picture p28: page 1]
SCALE 6 : 1; SHEET 1 OF 1; ALARM CLOCK V3; TOUCH KEYPAD PCB; PART #; DOCUMENT #; UNITS; DATE 12/13/2018; SCALE 2:1; PCB FR4 - 1.6mm; NOTES :; APVD BY :

Benoit Frigon
www.frigon.info

FILE : clkv3-dwg-07_touch-keypad-pcb

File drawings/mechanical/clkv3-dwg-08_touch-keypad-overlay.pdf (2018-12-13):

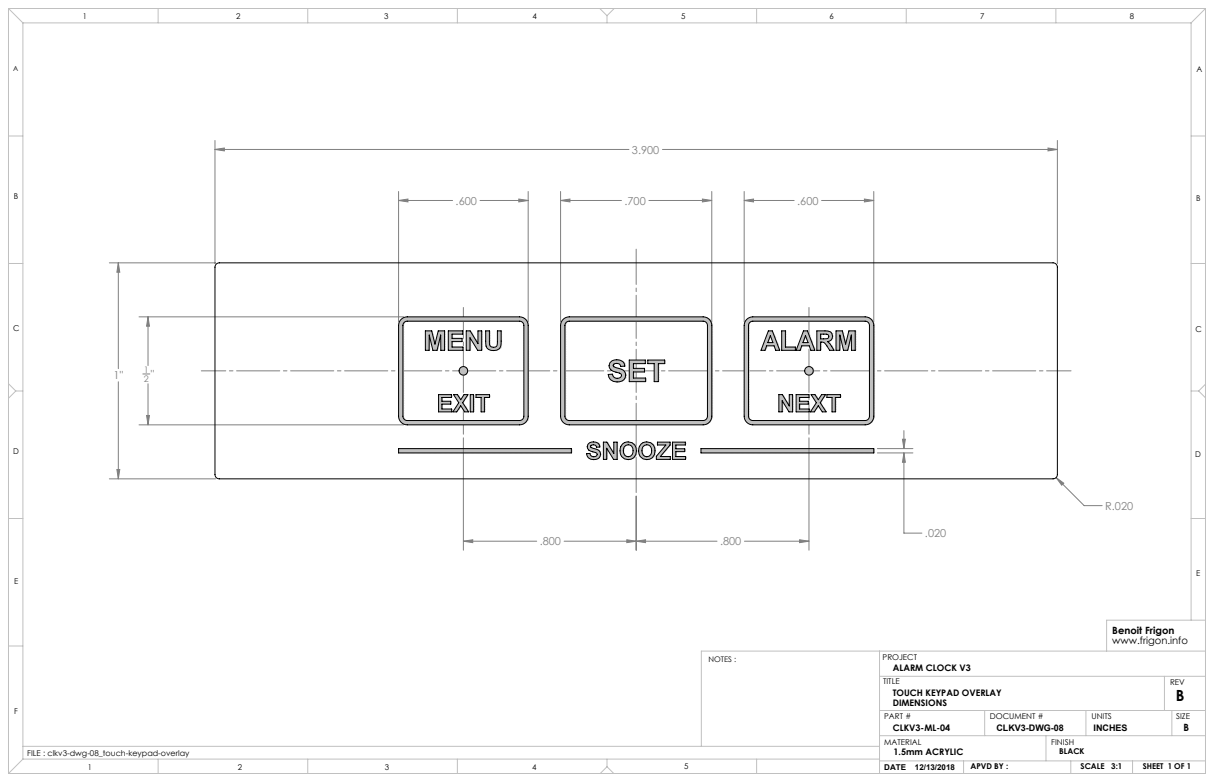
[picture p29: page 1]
SHEET 1 OF 1; ALARM CLOCK V3; TOUCH KEYPAD OVERLAY; PART #; DOCUMENT #; UNITS; DATE 12/13/2018; SCALE 3:1; 1.5mm ACRYLIC; NOTES :; APVD BY :

Benoit Frigon
www.frigon.info

FILE : clkv3-dwg-08_touch-keypad-overlay

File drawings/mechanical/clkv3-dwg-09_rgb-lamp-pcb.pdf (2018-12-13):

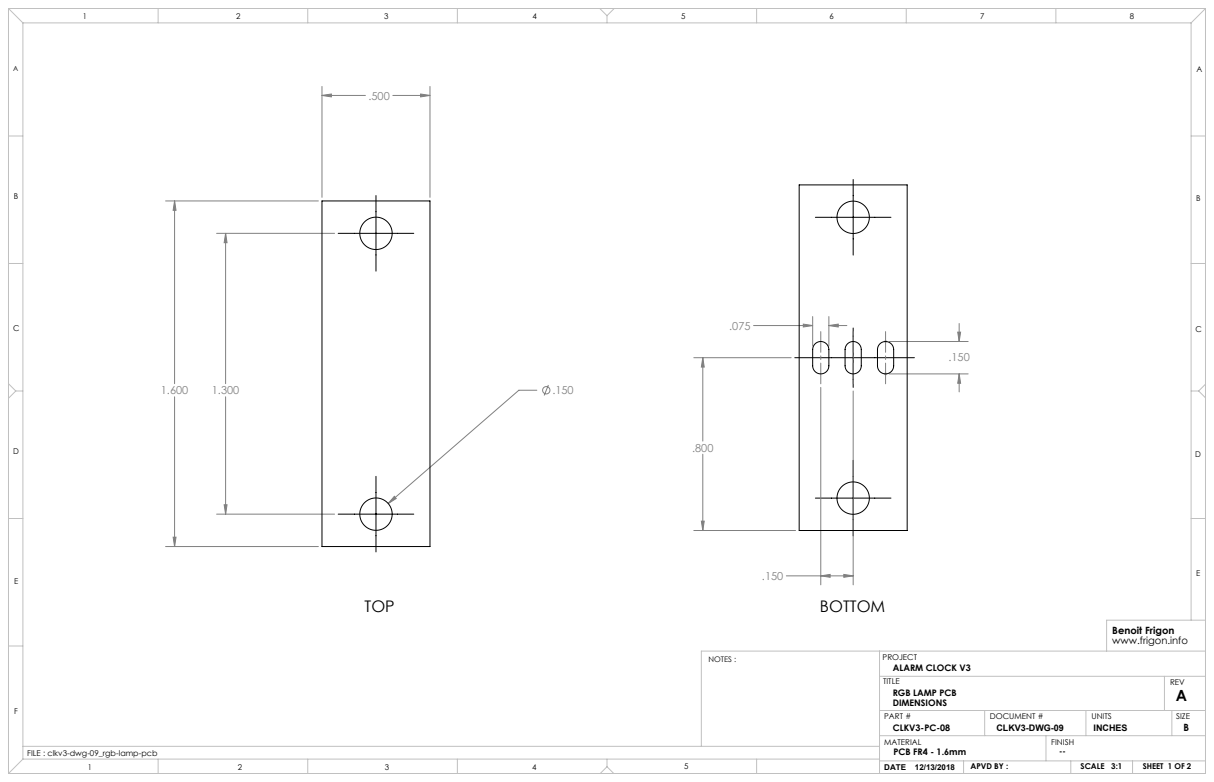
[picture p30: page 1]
SHEET 1 OF 2; ALARM CLOCK V3; RGB LAMP PCB; PART #; DOCUMENT #; UNITS; DATE 12/13/2018; SCALE 3:1; PCB FR4 - 1.6mm; NOTES :; APVD BY :

Benoit Frigon
www.frigon.info

FILE : clkv3-dwg-09_rgb-lamp-pcb

SHEET 2 OF 2; ALARM CLOCK V3; RGB LAMP PCB; PART #; DOCUMENT #; UNITS; DATE 12/13/2018; SCALE 3:1; PCB FR4 - 1.6mm; NOTES :; COMPONENTS POSITION; APVD BY :

Benoit Frigon
www.frigon.info

ITEM NO. | PART NUMBER | MFG | DESCRIPTION | QTY.

1 | CLKV3-PC-08 | -- | RGB Lamp PCB | 1
2 | IN-PI554FCH | Inolux | RGB LED with integrated driver | 3
3 | 4871 | Keystone Electronics | Round standoff #2-56 steel 1/16" | 2

FILE : clkv3-dwg-09_rgb-lamp-pcb

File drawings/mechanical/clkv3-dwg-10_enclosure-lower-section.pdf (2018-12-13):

.129 THRU ALL; DETAIL A SCALE 4 : 1; DETAIL B SCALE 4 : 1; SHEET 1 OF 1; ALARM CLOCK V3; ENCLOSURE - LOWER SECTION; PART #; DOCUMENT #; UNITS; DATE 12/13/2018; SCALE 5:6; APVD BY :

Benoit Frigon
www.frigon.info

NOTES :
MATERIAL VOLUME : 2.31 in³

FILE : clkv3-dwg-10_enclosure-lower-section

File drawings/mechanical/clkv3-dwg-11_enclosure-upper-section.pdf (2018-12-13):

SECTION A-A; DETAIL B SCALE 4 : 1; DETAIL C SCALE 6 : 1; SHEET 1 OF 2; ALARM CLOCK V3; ENCLOSURE - UPPER SECTION; PART #; DOCUMENT #; UNITS; DATE 12/13/2018; SCALE 5:6; APVD BY :

Benoit Frigon
www.frigon.info

NOTES :
MATERIAL VOLUME : 1.58 in³

FILE : clkv3-dwg-11_enclosure-upper-section

SECTION D-D; DETAIL E SCALE 16 : 1; SHEET 2 OF 2; ALARM CLOCK V3; ENCLOSURE - UPPER SECTION; PART #; DOCUMENT #; UNITS; DATE 12/13/2018; SCALE 1:1; APVD BY :

Benoit Frigon
www.frigon.info

NOTES :
MATERIAL VOLUME : 1.58 in³

FILE : clkv3-dwg-11_enclosure-upper-section

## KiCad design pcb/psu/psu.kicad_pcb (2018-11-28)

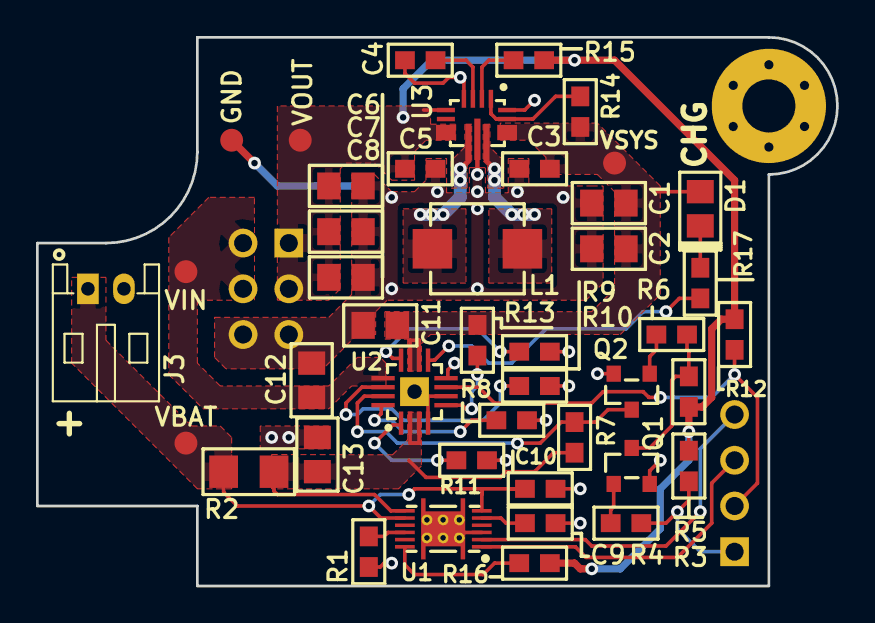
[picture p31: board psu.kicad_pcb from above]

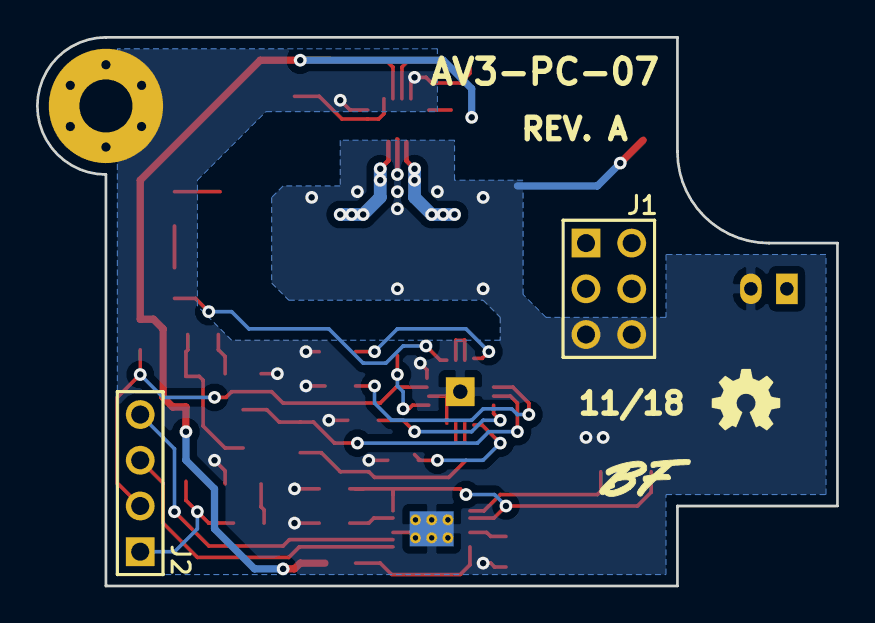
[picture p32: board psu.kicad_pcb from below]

Board: 2 copper layers, 44.4 x 30.5 mm, 46 parts (2 on the bottom side), 29 nets.

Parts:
C1, C2, C11, C12, C13: 10uF; C-0805
C3, C5: 10uF; C-0603
C4: 100nF; C-0603
C6, C7, C8: 22uF; C-0805
C9: 470nF; C-0603
C10: 1uF; C-0603
D1: LED; LED-0805
H1: Hole; Hole-Screw-#4
J1: VIN; HDR-M-2x03
J2: SIGNAL; HDR-M-1x04
J3: BATTERY; S2B-PH-K
L1: 1.5uH; SPM5030-HZ
Q1, Q2: MMST3904; SOT23
R1, R11, R13, R14, R15, R16: 10k; R-0603
R2: 0.01 1%; R-1206
R3, R4, R5, R6, R12: 100k; R-0603
R7: 787k; R-0603
R8: 5.6k; R-0603
R9: 1.1k; R-0603
R10: 0; R-0603
R17: 680; R-0603
TP1: VBAT; TEST-POINT-50
TP2: VIN; TEST-POINT-50
TP3: VSYS; TEST-POINT-50
TP4: GND; TEST-POINT-50
TP5: VOUT; TEST-POINT-50
U1: BQ27441-G1; PDSO-N12
U2: BQ24075; QFN16-EP-3x3
U3: TPS630701; VQFN15N

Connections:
+5V: C5.2, C6.2, C7.2, C8.2, J1.1, J1.3, R3.1, R5.1, R12.2, R15.2, R16.2, TP5.1, U3.5, U3.7, U3.8
+BATT: C13.2, R2.2, R7.1, U1.7, U2.2, U2.3
+SYS: C1.2, C2.2, C3.2, C11.2, D1.A, R13.2, R14.2, TP3.1, U2.10, U2.11, U3.12, U3.13
+VIN: C12.2, J1.2, J1.4, TP2.1, U2.13
/BATT_IN: C10.2, J3.1, R2.1, TP1.1, U1.6, U1.8
/L1: L1.1, U3.11
/L2: L1.2, U3.9
/ON_BATT: J2.2, R12.1, U2.7
/SCL: J2.4, U1.2
/SDA: J2.3, U1.1
/SYSOFF: J2.1, R3.2, R4.1
/~CHG: R17.2, U2.9
GND: C1.1, C2.1, C3.1, C4.1, C5.1, C6.1, C7.1, C8.1, C9.2, C10.1, C11.1, C12.1, C13.1, H1.P, J1.5, J1.6, J3.2, Q1.2, Q2.2, R1.2, R8.1, R9.1, R10.1, R11.1, TP4.1, U1.3, U1.EP, U2.4, U2.6, U2.8, U2.EP, U3.4, U3.10, U3.15
unnamed: C4.2, U3.3
unnamed: C9.1, U1.5
unnamed: D1.K, R17.1
unnamed: Q1.1, R4.2
unnamed: Q1.3, R5.2, R6.1
unnamed: Q2.1, R6.2
unnamed: Q2.3, R7.2, U2.15
unnamed: R1.1, U1.10
unnamed: R8.2, U2.16
unnamed: R9.2, U2.12
unnamed: R10.2, U2.14
unnamed: R11.2, U2.1
unnamed: R13.1, U2.5
unnamed: R14.1, U3.1, U3.14
unnamed: R15.1, U3.2
unnamed: R16.1, U1.12

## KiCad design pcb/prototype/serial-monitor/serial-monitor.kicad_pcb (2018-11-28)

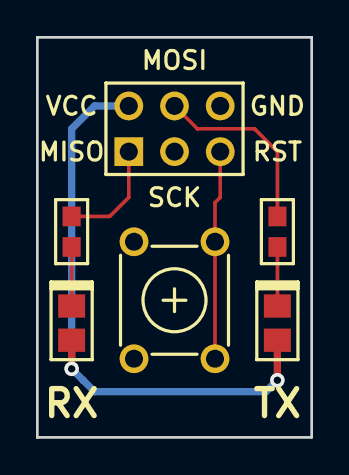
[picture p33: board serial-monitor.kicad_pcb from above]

Board: 2 copper layers, 15.2 x 22.2 mm, 6 parts (0 on the bottom side), 7 nets.

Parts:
D1, D2: LED; LED-0805
J1: ICSP; HDR-M-2x03
R1, R2: 680; R-0603
SW1: MOM-SPST; B3F-10XX

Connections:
+5V: D1.A, D2.A, J1.2
GND: J1.6, SW1.1
unnamed: D1.K, R1.1
unnamed: D2.K, R2.1
unnamed: J1.1, R1.2
unnamed: J1.4, R2.2
unnamed: J1.5, SW1.2

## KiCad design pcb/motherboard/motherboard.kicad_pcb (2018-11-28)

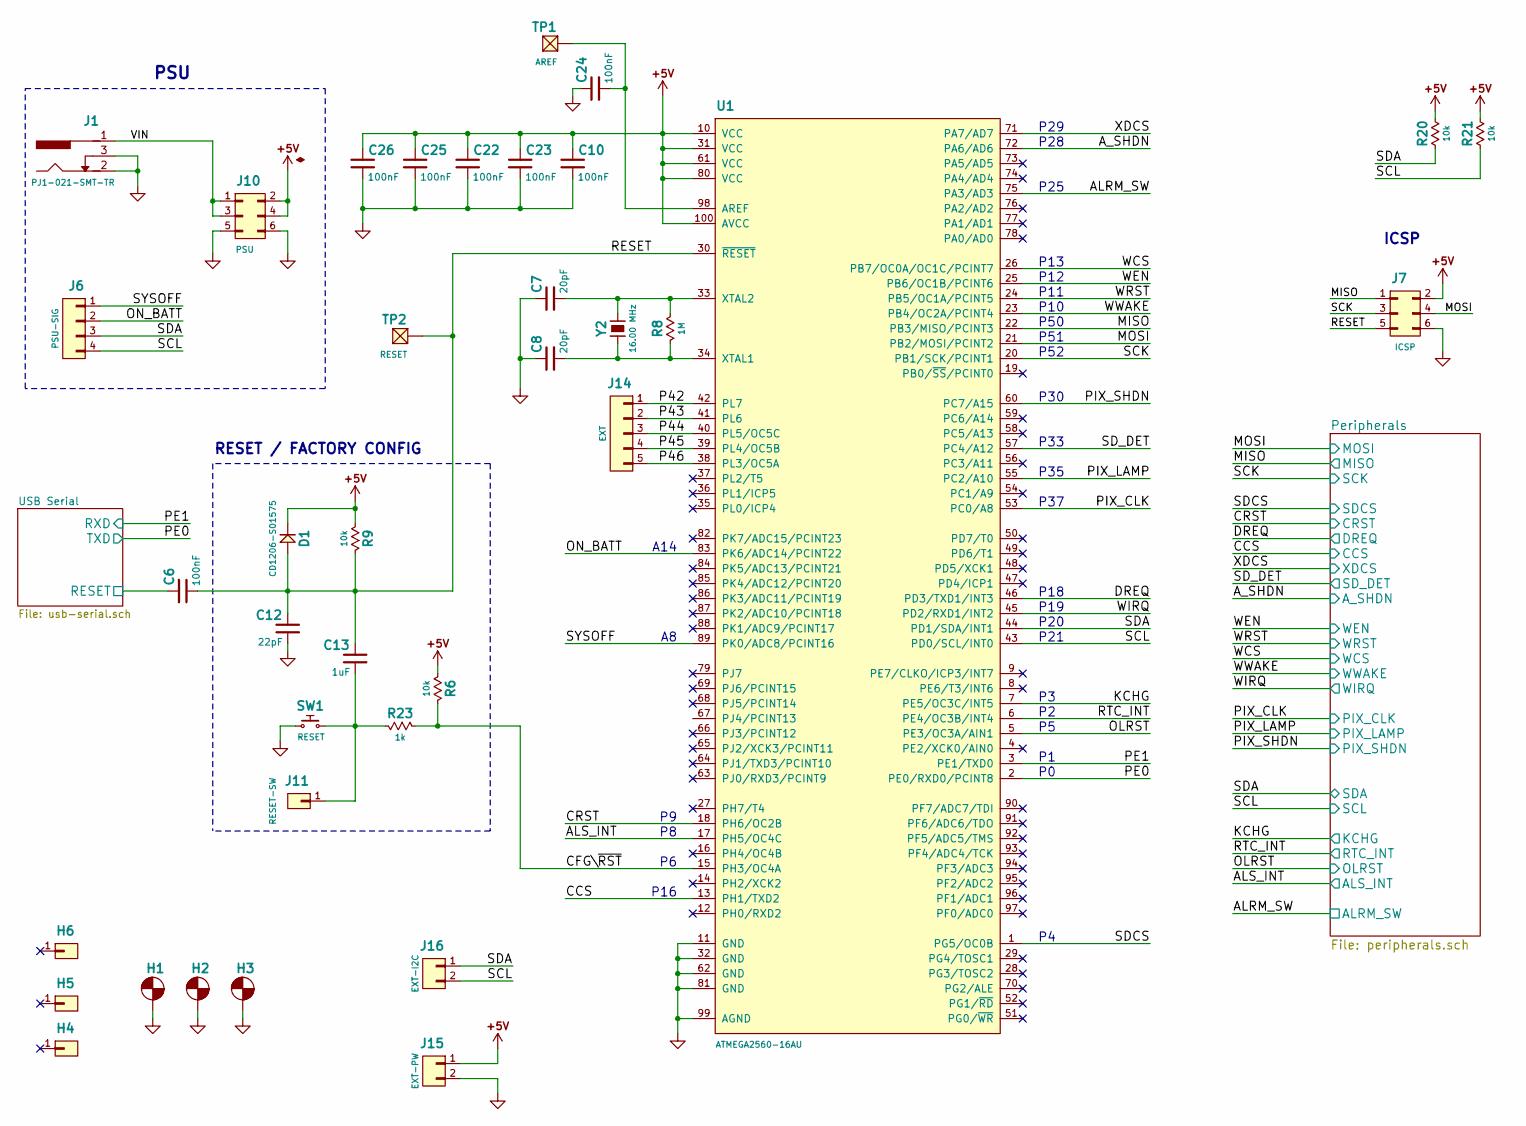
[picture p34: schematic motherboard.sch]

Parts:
C6, C10, C22, C23, C24, C25, C26: 100nF; C-0603
C7, C8: 20pF; C-0603
C12: 22pF; C-0603
C13: 1uF; C-0603
D1: CD1206-S01575; D-1206; Part CD1206-S01575
H1, H2, H3: Hole; Hole-Screw-#4
H4, H5: HEADER-1x01; SolderPad-100x500
H6: HEADER-1x01; SolderPad-100x300
J1: -; CUI-P1J-021-SMT; Part PJ1-021-SMT-TR
J6: PSU-SIG; HDR-M-1x04; Part BCS-104-L-S-TE
J7: ICSP; HDR-M-2x03; Part CES-103-01-T-D
J10: PSU; HDR-M-2x03; Part BCS-103-L-D-TE
J11: RESET-SW; WP-50mil-1x01
J14: EXT; WP-40mil-1x05
J15: EXT-PW; WP-50mil-1x02
J16: EXT-I2C; WP-50mil-1x02
R6, R9, R20, R21: 10k; R-0603
R8: 1M; R-0603
R23: 1k; R-0603
SW1: RESET; B3F-10XX; Part B3F-1000
TP1: AREF; TEST-POINT-50
TP2: RESET; TEST-POINT-50
U1: ATMEGA2560-16AU; QFP-14-100
Y2: 16.00 MHz; smt-CSM-3X-7x4mm; Part ECS-160-20-3X-TR

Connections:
/ALRM_SW: U1.75 (PA3/AD3); also elsewhere on the board
/ALS_INT: U1.17 (PH5/OC4C); also elsewhere on the board
/A_SHDN: U1.72 (PA6/AD6); also elsewhere on the board
/CCS: U1.13 (PH1/TXD2); also elsewhere on the board
/CFG\~RST: R6.1, R23.1, U1.15 (PH3/OC4A)
/CRST: U1.18 (PH6/OC2B); also elsewhere on the board
/DREQ: U1.46 (PD3/TXD1/INT3); also elsewhere on the board
/KCHG: U1.7 (PE5/OC3C/INT5); also elsewhere on the board
/MISO: J7.1, U1.22 (PB3/MISO/PCINT3); also elsewhere on the board
/MOSI: J7.4, U1.21 (PB2/MOSI/PCINT2); also elsewhere on the board
/OLRST: U1.5 (PE3/OC3A/AIN1); also elsewhere on the board
/ON_BATT: J6.2, U1.83 (PK6/ADC14/PCINT22)
/P42: J14.1, U1.42 (PL7)
/P43: J14.2, U1.41 (PL6)
/P44: J14.3, U1.40 (PL5/OC5C)
/P45: J14.4, U1.39 (PL4/OC5B)
/P46: J14.5, U1.38 (PL3/OC5A)
/PE0: U1.2 (PE0/RXD0/PCINT8); also elsewhere on the board
/PE1: U1.3 (PE1/TXD0); also elsewhere on the board
/PIX_CLK: U1.53 (PC0/A8); also elsewhere on the board
/PIX_LAMP: U1.55 (PC2/A10); also elsewhere on the board
/PIX_SHDN: U1.60 (PC7/A15); also elsewhere on the board
/RESET: C6.1, C12.2, C13.2, D1.A, J7.5, R9.1, TP2.1, U1.30 (~RESET)
/RTC_INT: U1.6 (PE4/OC3B/INT4); also elsewhere on the board
/SCK: J7.3, U1.20 (PB1/SCK/PCINT1); also elsewhere on the board
/SCL: J6.4, J16.2, R21.1, U1.43 (PD0/SCL/INT0); also elsewhere on the board
/SDA: J6.3, J16.1, R20.1, U1.44 (PD1/SDA/INT1); also elsewhere on the board
/SDCS: U1.1 (PG5/OC0B); also elsewhere on the board
/SD_DET: U1.57 (PC4/A12); also elsewhere on the board
/SYSOFF: J6.1, U1.89 (PK0/ADC8/PCINT16)
/USB Serial/RESET: C6.2; also elsewhere on the board
/VIN: J1.1, J10.1, J10.3
/WCS: U1.26 (PB7/OC0A/OC1C/PCINT7); also elsewhere on the board
/WEN: U1.25 (PB6/OC1B/PCINT6); also elsewhere on the board
/WIRQ: U1.45 (PD2/RXD1/INT2); also elsewhere on the board
/WRST: U1.24 (PB5/OC1A/PCINT5); also elsewhere on the board
/WWAKE: U1.23 (PB4/OC2A/PCINT4); also elsewhere on the board
/XDCS: U1.71 (PA7/AD7); also elsewhere on the board
GND: C7.2, C8.2, C10.1, C12.1, C22.1, C23.1, C24.2, C25.1, C26.1, H1.P, H2.P, H3.P, J1.2, J1.3, J7.6, J10.5, J10.6, J15.2, SW1.2, U1.11 (GND), U1.32 (GND), U1.62 (GND), U1.81 (GND), U1.99 (AGND); also elsewhere on the board
unnamed: C7.1, R8.1, U1.33 (XTAL2), Y2.2
unnamed: C8.1, R8.2, U1.34 (XTAL1), Y2.1
unnamed: C13.1, J11.1, R23.2, SW1.1
unnamed: C24.1, TP1.1, U1.98 (AREF)

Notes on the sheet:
RESET / FACTORY CONFIG
P29
P28
P25
P13
P12
P11
P10
P50
P51
P52
P30
P33
P35
P37
P18
P19
P20
P21
P16
ICSP
A14
PSU

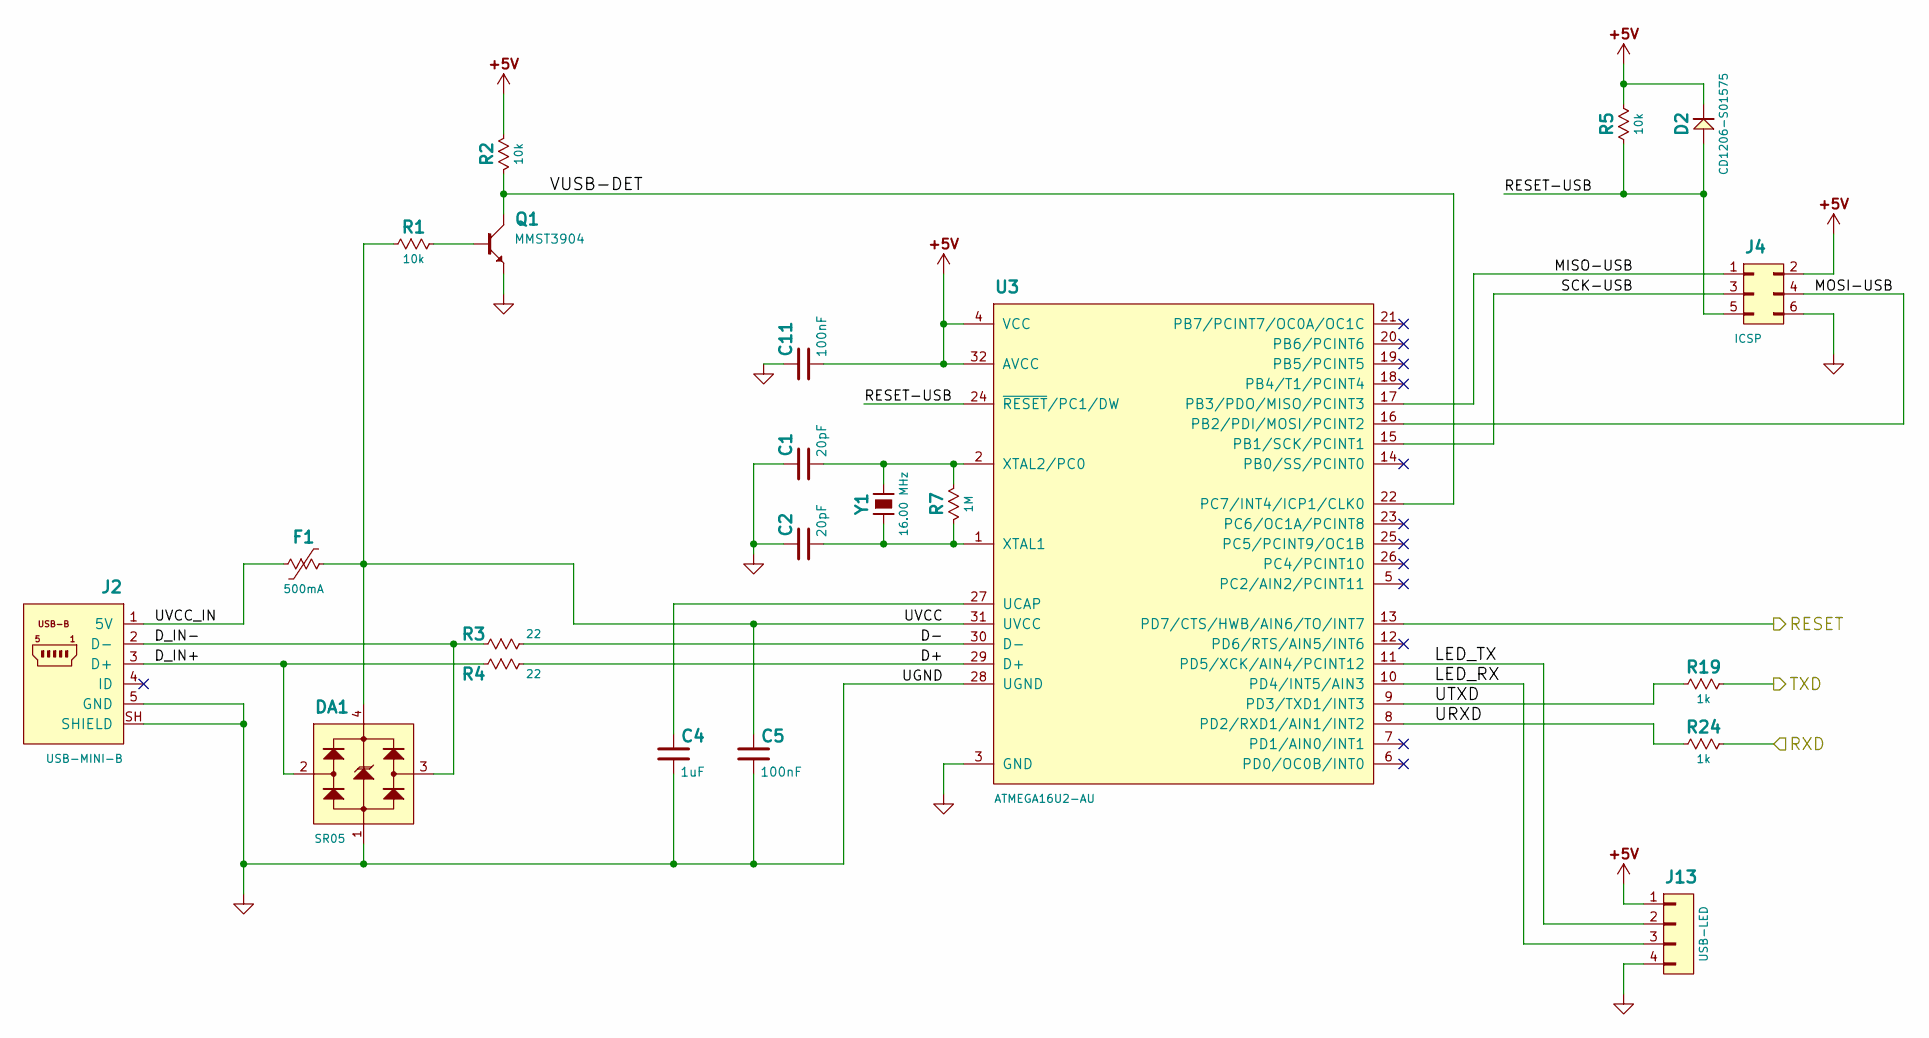
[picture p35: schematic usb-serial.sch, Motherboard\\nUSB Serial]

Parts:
C1, C2: 20pF; C-0603
C4: 1uF; C-0805
C5, C11: 100nF; C-0603
D2: CD1206-S01575; D-1206; Part CD1206-S01575
DA1: SR05; SOT-143
F1: 500mA; R-1206
J2: USB-MINI-B; USB-MB_UX60SC-MB-5ST; Part UX60SC-MB-5ST
J4: ICSP; HDR-M-2x03; Part CES-103-01-T-D
J13: USB-LED; WP-50mil-1x04
Q1: MMST3904; SOT23
R1, R2, R5: 10k; R-0603
R3, R4: 22; R-0603
R7: 1M; R-0603
R19, R24: 1k; R-0603
U3: ATMEGA16U2-AU; QFP-7-32
Y1: 16.00 MHz; smt-CSM-3X-7x4mm; Part ECS-160-20-3X-TR

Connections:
/PE0: R19.2; also elsewhere on the board
/PE1: R24.2; also elsewhere on the board
/USB Serial/D+: R4.2, U3.29 (D+)
/USB Serial/D-: R3.2, U3.30 (D-)
/USB Serial/D_IN+: DA1.2, J2.3 (D+), R4.1
/USB Serial/D_IN-: DA1.3, J2.2 (D-), R3.1
/USB Serial/LED_RX: J13.3, U3.10 (PD4/INT5/AIN3)
/USB Serial/LED_TX: J13.2, U3.11 (PD5/XCK/AIN4/PCINT12)
/USB Serial/MISO-USB: J4.1, U3.17 (PB3/PDO/MISO/PCINT3)
/USB Serial/MOSI-USB: J4.4, U3.16 (PB2/PDI/MOSI/PCINT2)
/USB Serial/RESET: U3.13 (PD7/CTS/HWB/AIN6/TO/INT7); also elsewhere on the board
/USB Serial/RESET-USB: D2.A, J4.5, R5.1, U3.24 (~RESET~/PC1/DW)
/USB Serial/SCK-USB: J4.3, U3.15 (PB1/SCK/PCINT1)
/USB Serial/URXD: R24.1, U3.8 (PD2/RXD1/AIN1/INT2)
/USB Serial/UTXD: R19.1, U3.9 (PD3/TXD1/INT3)
/USB Serial/UVCC: C5.2, DA1.4, F1.2, R1.1, U3.31 (UVCC)
/USB Serial/UVCC_IN: F1.1, J2.1 (5V)
/USB Serial/VUSB-DET: Q1.3 (C), R2.2, U3.22 (PC7/INT4/ICP1/CLK0)
GND: C1.2, C2.2, C4.1, C5.1, C11.2, DA1.1, J2.5 (GND), J2.SH (SHIELD), J4.6, J13.4, Q1.2 (E), U3.3 (GND), U3.28 (UGND); also elsewhere on the board
unnamed: C1.1, R7.1, U3.2 (XTAL2/PC0), Y1.2
unnamed: C2.1, R7.2, U3.1 (XTAL1), Y1.1
unnamed: C4.2, U3.27 (UCAP)
unnamed: Q1.1 (B), R1.2

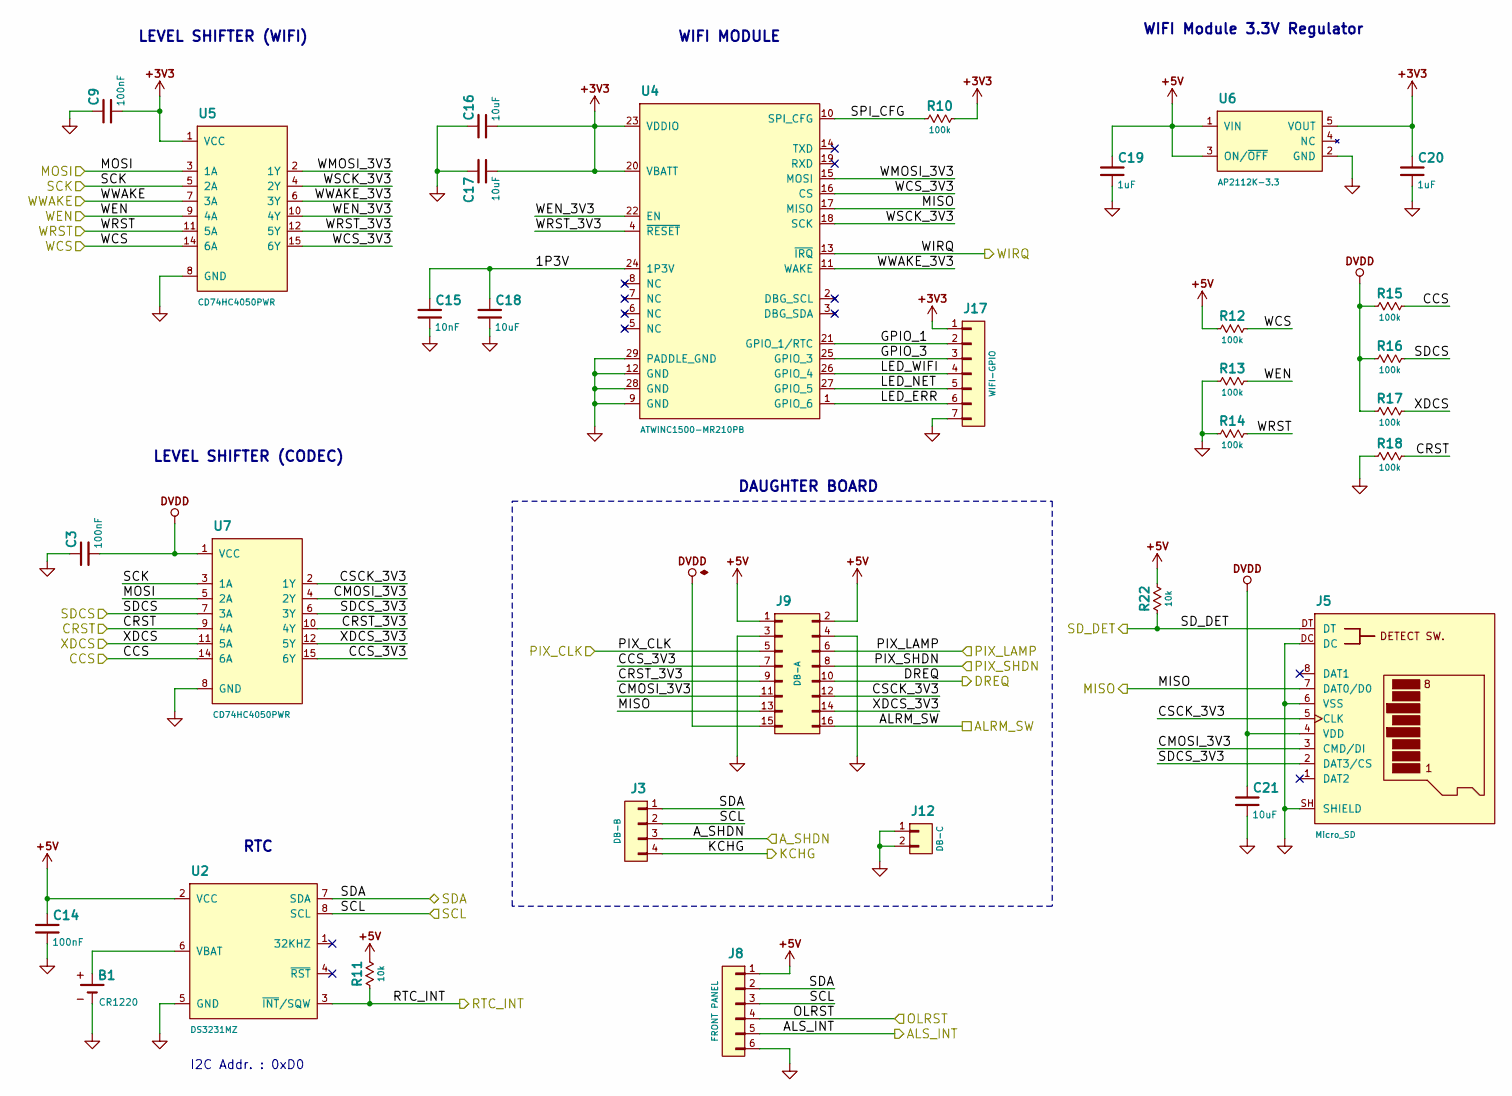
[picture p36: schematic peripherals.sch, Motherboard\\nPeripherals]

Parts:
B1: CR1220; S8411-45R; Part S8411-45R
C3, C9, C14: 100nF; C-0603
C15: 10nF; C-0603
C16, C17, C18, C21: 10uF; C-0805
C19, C20: 1uF; C-0805
J3: DB-B; HDR-M-1x04; Part DW-04-07-TM-S-200
J5: Micro_SD; MOLEX-MICROSD-475710001; Part 475710001
J8: FRONT PANEL; WP-EDGE-RL-50mil-1x06
J9: DB-A; HDR-M-2x08; Part DW-08-07-T-D-200
J12: DB-C; HDR-M-1x02; Part DW-02-07-T-S-200
J17: WIFI-GPIO; WP-40mil-1x07
R10, R12, R13, R14, R15, R16, R17, R18: 100k; R-0603
R11, R22: 10k; R-0603
U2: DS3231MZ; SOIC8
U4: ATWINC1500-MR210PB; ATWINC1500-MR
U5, U7: CD74HC4050PWR; TSSOP16
U6: AP2112K-3.3; SOT23-5

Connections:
+3V3: C9.1, C16.1, C17.1, C20.2, J17.1, R10.2, U4.20 (VBATT), U4.23 (VDDIO), U5.1 (VCC), U6.5 (VOUT)
/ALRM_SW: J9.16; also elsewhere on the board
/ALS_INT: J8.5; also elsewhere on the board
/A_SHDN: J3.3; also elsewhere on the board
/CCS: R15.2, U7.14 (6A); also elsewhere on the board
/CRST: R18.2, U7.9 (4A); also elsewhere on the board
/DREQ: J9.10; also elsewhere on the board
/KCHG: J3.4; also elsewhere on the board
/MISO: J5.7 (DAT0/D0), J9.13, U4.17 (MISO); also elsewhere on the board
/MOSI: U5.3 (1A), U7.5 (2A); also elsewhere on the board
/OLRST: J8.4; also elsewhere on the board
/PIX_CLK: J9.5; also elsewhere on the board
/PIX_LAMP: J9.6; also elsewhere on the board
/PIX_SHDN: J9.8; also elsewhere on the board
/Peripherals/1P3V: C15.2, C18.2, U4.24 (1P3V)
/Peripherals/CCS_3V3: J9.7, U7.15 (6Y)
/Peripherals/CMOSI_3V3: J5.3 (CMD/DI), J9.11, U7.4 (2Y)
/Peripherals/CRST_3V3: J9.9, U7.10 (4Y)
/Peripherals/CSCK_3V3: J5.5 (CLK), J9.12, U7.2 (1Y)
/Peripherals/GPIO_1: J17.2, U4.21 (GPIO_1/RTC)
/Peripherals/GPIO_3: J17.3, U4.25 (GPIO_3)
/Peripherals/LED_ERR: J17.6, U4.1 (GPIO_6)
/Peripherals/LED_NET: J17.5, U4.27 (GPIO_5)
/Peripherals/LED_WIFI: J17.4, U4.26 (GPIO_4)
/Peripherals/SDCS_3V3: J5.2 (DAT3/CS), U7.6 (3Y)
/Peripherals/SPI_CFG: R10.1, U4.10 (SPI_CFG)
/Peripherals/WCS_3V3: U4.16 (CS), U5.15 (6Y)
/Peripherals/WEN_3V3: U4.22 (EN), U5.10 (4Y)
/Peripherals/WMOSI_3V3: U4.15 (MOSI), U5.2 (1Y)
/Peripherals/WRST_3V3: U4.4 (~RESET), U5.12 (5Y)
/Peripherals/WSCK_3V3: U4.18 (SCK), U5.4 (2Y)
/Peripherals/WWAKE_3V3: U4.11 (WAKE), U5.6 (3Y)
/Peripherals/XDCS_3V3: J9.14, U7.12 (5Y)
/RTC_INT: R11.1, U2.3 (~INT~/SQW); also elsewhere on the board
/SCK: U5.5 (2A), U7.3 (1A); also elsewhere on the board
/SCL: J3.2, J8.3, U2.8 (SCL); also elsewhere on the board
/SDA: J3.1, J8.2, U2.7 (SDA); also elsewhere on the board
/SDCS: R16.2, U7.7 (3A); also elsewhere on the board
/SD_DET: J5.DT, R22.1; also elsewhere on the board
/WCS: R12.2, U5.14 (6A); also elsewhere on the board
/WEN: R13.2, U5.9 (4A); also elsewhere on the board
/WIRQ: U4.13 (~IRQ); also elsewhere on the board
/WRST: R14.2, U5.11 (5A); also elsewhere on the board
/WWAKE: U5.7 (3A); also elsewhere on the board
/XDCS: R17.2, U7.11 (5A); also elsewhere on the board
GND: B1.N, C3.2, C9.2, C14.1, C15.1, C16.2, C17.2, C18.1, C19.1, C20.1, C21.1, J5.6 (VSS), J5.DC, J5.SH (SHIELD), J8.6, J9.3, J9.4, J12.1, J12.2, J17.7, R13.1, R14.1, R18.1, U2.5 (GND), U4.9 (GND), U4.12 (GND), U4.28 (GND), U4.29 (PADDLE_GND), U5.8 (GND), U6.2 (GND), U7.8 (GND); also elsewhere on the board
unnamed: B1.P, U2.6 (VBAT)

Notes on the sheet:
WIFI MODULE
RTC
DAUGHTER BOARD
LEVEL SHIFTER (WIFI)
LEVEL SHIFTER (CODEC)
WIFI Module 3.3V Regulator
I2C Addr. : 0xD0

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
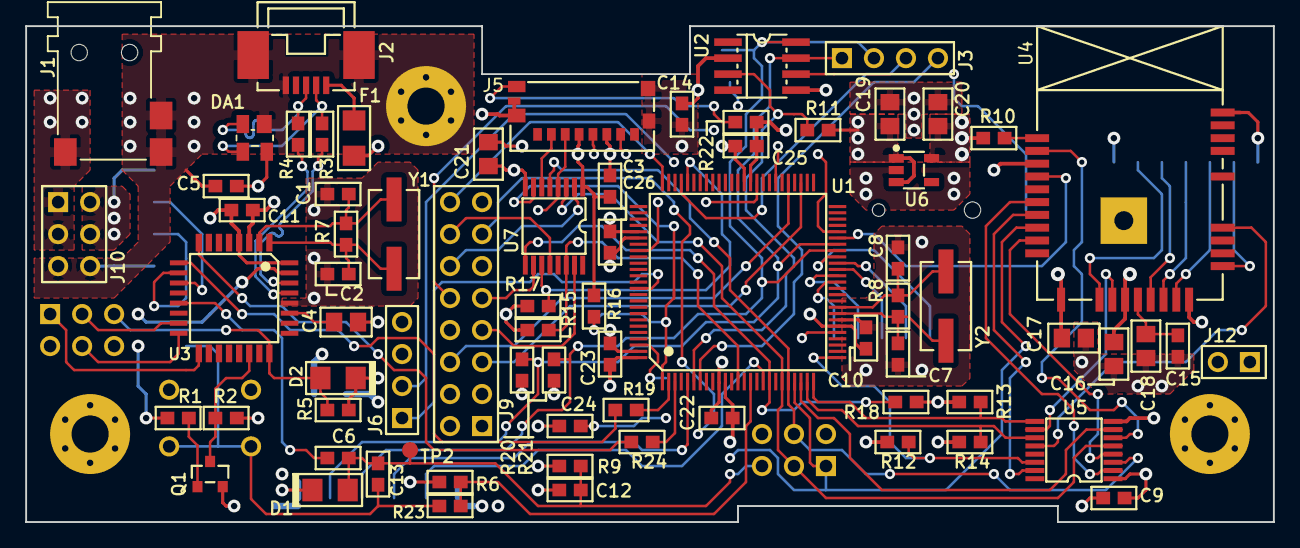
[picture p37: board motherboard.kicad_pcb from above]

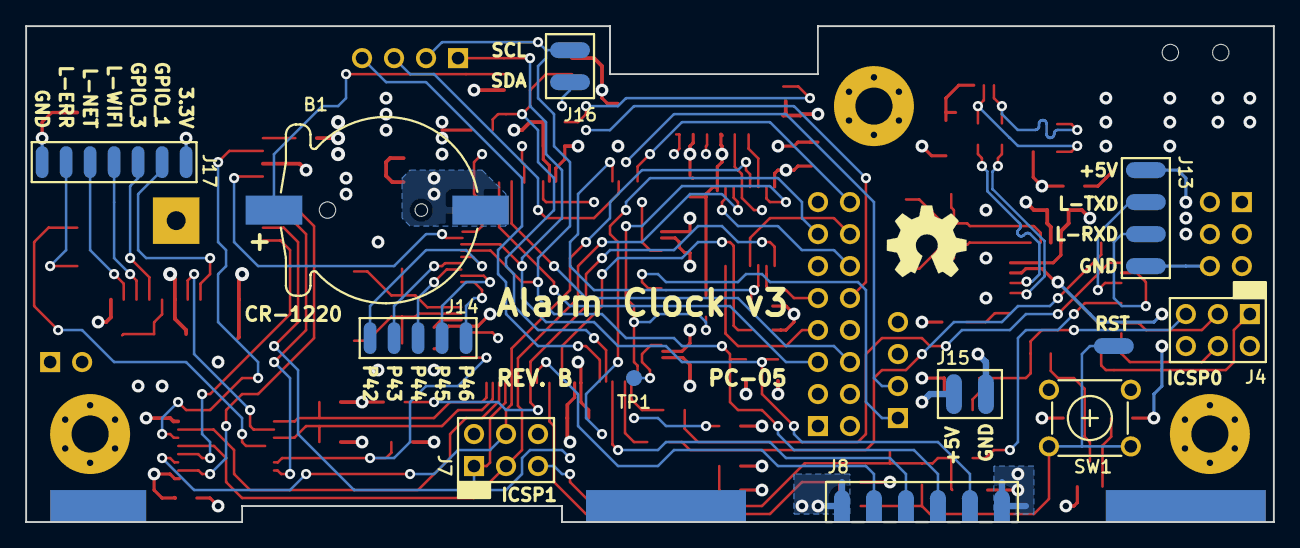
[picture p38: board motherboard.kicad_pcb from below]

Board: 4 copper layers, 99.1 x 39.4 mm, 91 parts (15 on the bottom side), 85 nets.

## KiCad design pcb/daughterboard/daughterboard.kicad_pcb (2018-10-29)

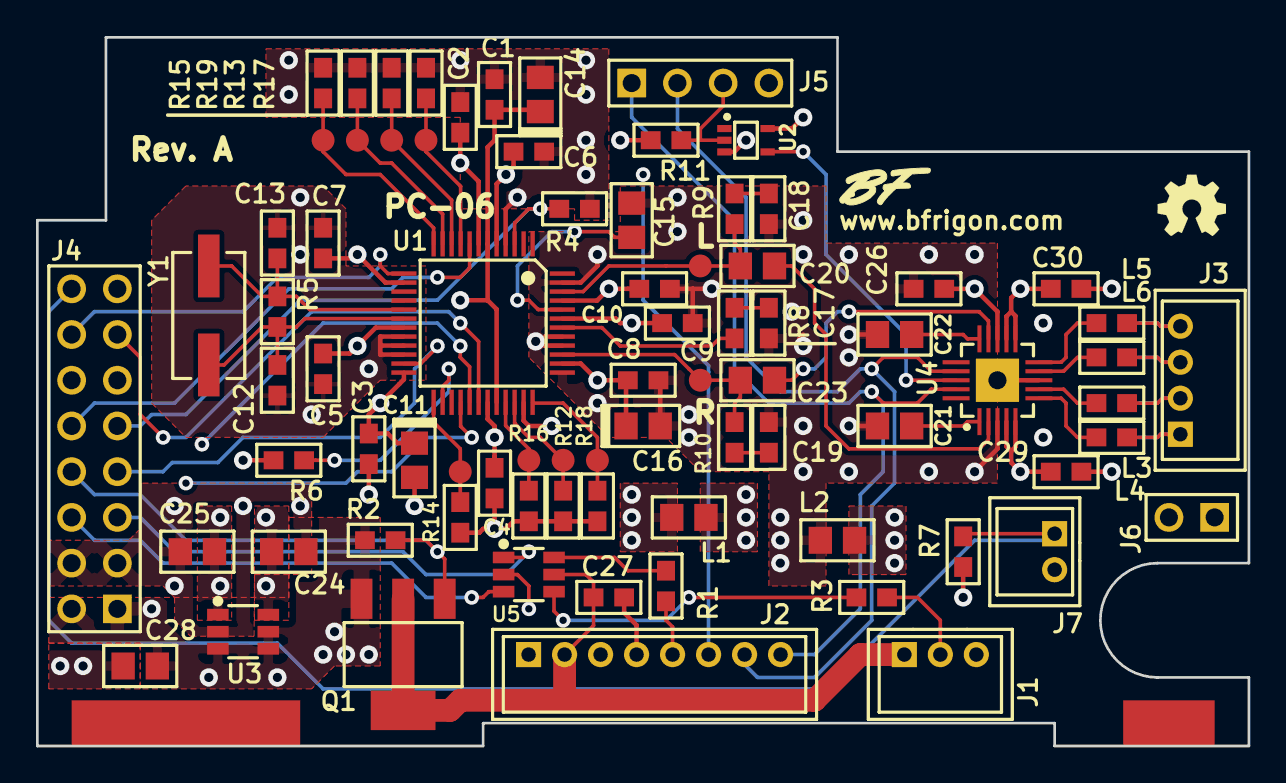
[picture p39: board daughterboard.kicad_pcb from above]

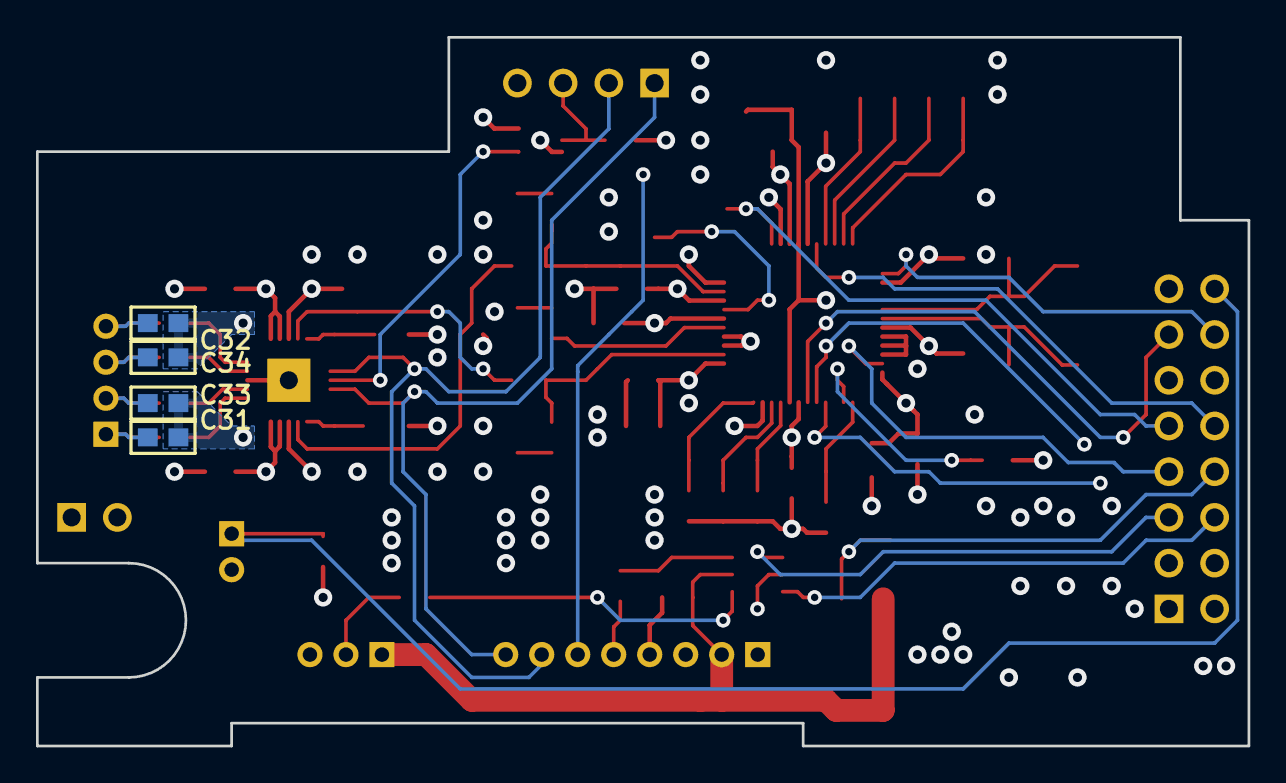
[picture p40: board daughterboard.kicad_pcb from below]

Board: 4 copper layers, 67.3 x 39.4 mm, 85 parts (4 on the bottom side), 57 nets.

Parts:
C1, C2, C3, C4, C5, C6, C7, C8, C9, C10, C26, C27, C29, C30: 100nF; C-0603
C11, C14, C16: 10uF 6V3; CPL-0805
C12, C13: 20pF; C-0603
C15, C20, C21, C22, C23: 1uF; C-0805
C17: 47nF; C-0603
C18, C19: 10nF; C-0603
C24, C25, C28: 10uF; C-0805
C31, C32, C33, C34: 1nF; C-0603
H1: Solder pad 2; SolderPad-100x500
H2: Solder Pad 2; SolderPad-100x200
J1: LAMP; DF3A-3P-2DSA
J2: DISPLAY; DF3A-8P-2DSA
J3: SPKR; DF3A-4P-2DSA
J4: DB-A; HDR-M-2x08
J5: DB-B; HDR-M-1x04
J6: DB-C; HDR-M-1x02
J7: ALARM SW; DF3A-2P-2DSA
L1, L2: 2508053007Y0; FER-0805
L3, L4, L5, L6: MPZ1608S221A; FER-0603
Q1: NTF6P02; SOT-223
R1, R3: 470; R-0603
R2, R7, R11: 10k; R-0603
R4, R6, R12, R13, R14, R15, R16, R17, R18, R19: 100k; R-0603
R5: 1M; R-0603
R8: 10; R-0603
R9, R10: 20; R-0603
TP1, TP2, TP3, TP4, TP5, TP6, TP7, TP8, TP9, TP10: TEST-POINT; TEST-POINT-50
U1: VS1053B; QFP-7-48
U2: 74AHC1G04SE-7; SOT-353
U3: AP7312-1833W6; SOT23-6
U4: TPA2016D2; QFN20-EP-4x4
U5: SN74LVC2G34DBV; SOT23-6
Y1: 12.288 MHz; smt-CSM-3X-7x4mm

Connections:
+1V8: C2.2, C3.2, C4.2, C6.2, C11.A, C24.2, U1.5, U1.7, U1.24, U1.31, U3.6
+3V3: C1.2, C5.2, C7.2, C14.A, C25.2, J4.15, L1.2, R6.1, U1.6, U1.14, U1.19, U1.32, U3.1
+5V: C28.2, C29.2, C30.2, J2.1, J4.1, J4.2, Q1.3, R2.2, R7.2, R11.2, U2.5, U3.3, U3.4, U3.5, U4.4, U4.5, U4.11, U4.12
/ALRM_SW: J4.16, J7.1, R7.1
/A_SHDN: J5.3, R11.1, U2.2
/CCS_3V3: J4.7, U1.23
/CMOSI_3V3: J4.11, U1.29
/CRST_3V3: J4.9, R4.1, U1.3
/DREQ: J4.10, U1.8
/GBUF: R8.2, U1.42
/GPIO0: R16.2, TP1.1, U1.33
/GPIO1: R12.2, TP2.1, U1.34
/GPIO2: R17.2, TP3.1, U1.9
/GPIO3: R13.2, TP4.1, U1.10
/GPIO4: R18.2, TP5.1, U1.36
/GPIO5: R14.2, TP6.1, U1.25
/GPIO6: R19.2, TP7.1, U1.11
/GPIO7: R15.2, TP8.1, U1.12
/KCHG: J2.6, J5.4
/LEFT: C20.2, R9.2, TP9.1, U1.46
/MISO: J4.13, U1.30
/OUT_L+: C33.1, J3.2, L3.2
/OUT_L-: C31.1, J3.1, L4.2
/OUT_R+: C34.2, J3.3, L6.2
/OUT_R-: C32.2, J3.4, L5.2
/PIX_CLK: J4.5, U5.1
/PIX_LAMP: J4.6, U5.3
/PIX_SHDN: J4.8, Q1.1, R2.1
/PIX_VCC: C27.2, J1.1, J2.2, Q1.2, Q1.4, U5.5
/RIGHT: C23.2, R10.2, TP10.1, U1.39
/SCL: J2.7, J5.2, U4.17
/SCLK_3V3: J4.12, U1.28
/SDA: J2.8, J5.1, U4.19
/XDCS_3V3: J4.14, U1.13
AGND: C8.1, C9.1, C10.1, C15.1, C16.K, C17.1, C18.1, C19.1, C21.2, C22.2, C26.1, C31.2, C32.1, C33.2, C34.1, L2.1, U1.37, U1.40, U1.41, U1.47, U4.3
AVDD: C8.2, C9.2, C10.2, C16.A, C26.2, L1.1, U1.38, U1.43, U1.45, U4.13
GND: C1.1, C2.1, C3.1, C4.1, C5.1, C6.1, C7.1, C11.K, C12.2, C13.2, C14.K, C24.1, C25.1, C27.1, C28.1, C29.1, C30.1, J1.3, J2.3, J2.4, J4.3, J4.4, J6.1, J6.2, J7.2, L2.2, R4.2, R12.1, R13.1, R14.1, R15.1, R16.1, R17.1, R18.1, R19.1, U1.4, U1.16, U1.20, U1.21, U1.22, U1.35, U2.3, U3.2, U4.8, U4.EP, U5.2
unnamed: C12.1, R5.2, U1.18, Y1.1
unnamed: C13.1, R5.1, U1.17, Y1.2
unnamed: C15.2, U1.44
unnamed: C17.2, R8.1
unnamed: C18.2, R9.1
unnamed: C19.2, R10.1
unnamed: C20.1, U4.2
unnamed: C21.1, U4.1
unnamed: C22.1, U4.15
unnamed: C23.1, U4.14
unnamed: J1.2, R3.2
unnamed: J2.5, R1.2
unnamed: L3.1, U4.7
unnamed: L4.1, U4.6
unnamed: L5.1, U4.10
unnamed: L6.1, U4.9
unnamed: R1.1, U5.6
unnamed: R3.1, U5.4
unnamed: R6.2, U1.26
unnamed: U2.4, U4.18

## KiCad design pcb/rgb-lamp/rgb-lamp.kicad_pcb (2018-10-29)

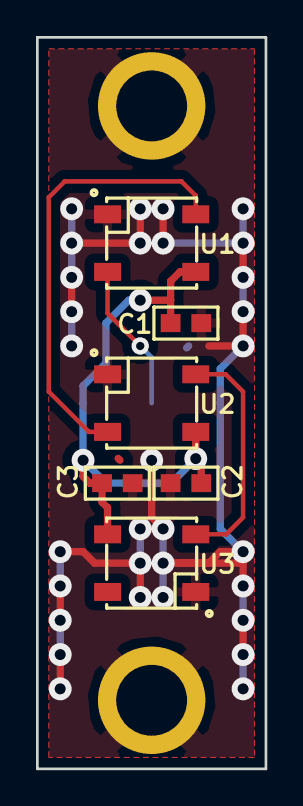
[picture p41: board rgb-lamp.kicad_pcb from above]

Board: 2 copper layers, 12.7 x 40.6 mm, 9 parts (1 on the bottom side), 5 nets.

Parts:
C1, C2, C3: 100nF; C-0603
H1, H2: Hole; SM-Standoff-#2
J1: HEADER-1x03; WP-75mil-1x03
U1, U2, U3: IN-PI554FCH; LED-5050

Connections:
+5V: C1.1, C2.1, C3.1, J1.3, U1.1, U2.1, U3.1
GND: C1.2, C2.2, C3.2, H1.P, H2.P, J1.1, U1.3, U2.3, U3.3
unnamed: J1.2, U1.4
unnamed: U1.2, U2.4
unnamed: U2.2, U3.4

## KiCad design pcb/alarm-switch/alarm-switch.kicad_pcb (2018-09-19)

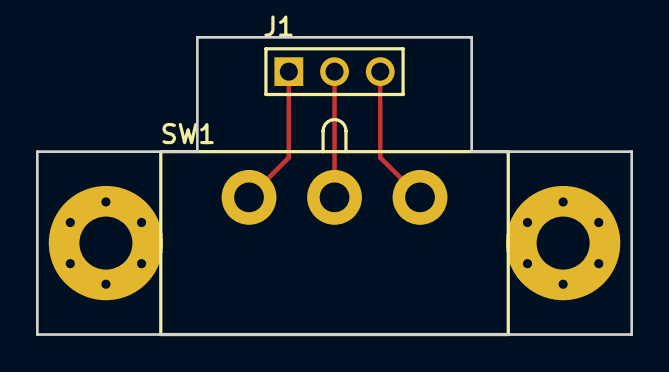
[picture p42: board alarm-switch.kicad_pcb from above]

Board: 2 copper layers, 33.0 x 16.5 mm, 4 parts (0 on the bottom side), 4 nets.

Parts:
H1, H2: Hole; Hole-Screw-#4
J1: HEADER-1x03; HDR-M-1x03
SW1: L102011ML04Q; CK-L102XXXML04

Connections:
GND: H1.P, H2.P
unnamed: J1.1, SW1.1
unnamed: J1.2, SW1.2
unnamed: J1.3, SW1.3

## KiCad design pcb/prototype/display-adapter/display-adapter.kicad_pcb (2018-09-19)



Board: 2 copper layers, 18.4 x 44.5 mm, 11 parts (3 on the bottom side), 13 nets.

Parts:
C1: 100nF; C-0603
J1: DISPLAY; DF3A-8P-2DSA
J2, J3: HEADER-1x02; HDR-M-1x02
J4: LAMP; DF3A-3P-2DSA
J5: HEADER-1x06; HDR-M-1x06
Q1: NTF6P02; SOT-223
R1: 10k; R-0603
R2, R3: 470; R-0603
U1: SN74LVC2G34DBV; SOT23-6

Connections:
+5V: J1.1, J2.1, J3.1, Q1.3, R1.2
/KCHG: J1.6, J5.4
/PIX_CLK: J5.5, U1.1
/PIX_LAMP: J5.6, U1.3
/PIX_SHDN: J5.1, Q1.1, R1.1
/PIX_VCC: C1.2, J1.2, J4.1, Q1.2, Q1.4, U1.5
/SCL: J1.7, J5.3
/SDA: J1.8, J5.2
GND: C1.1, J1.3, J1.4, J2.2, J3.2, J4.3, U1.2
unnamed: J1.5, R2.2
unnamed: J4.2, R3.2
unnamed: R2.1, U1.6
unnamed: R3.1, U1.4

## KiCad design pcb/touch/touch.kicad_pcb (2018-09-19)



Board: 2 copper layers, 99.1 x 25.4 mm, 20 parts (3 on the bottom side), 14 nets.

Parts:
C1, C3: 1uF; C-0805
C2: 100nF; C-0603
C4: 3.3uF; C-0805
J1: HEADER-1x05; WP-50mil-1x05
Q1, Q2: BSS138; SOT23
R1, R3, R7, R8: 10k; R-0603
R2: 100k; R-0603
R4, R5, R6: 470; R-0603
SW1: ALARM; TouchPad-700x600
SW2: MENU; TouchPad-700x600
SW3: SET; TouchPad-800x600
U1: AT42QT1070; SOIC14N
U2: LP2981-33DBVT; SOT23-5

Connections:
+3V3: C1.1, C2.1, C4.2, Q1.1, Q2.1, R2.1, R7.2, R8.2, U1.1, U2.5
+5V: C3.2, J1.5, R1.2, R3.2, U2.1, U2.3
/E_LEFT: R6.2, SW1.1
/E_RIGHT: R4.2, SW2.1
/E_SET: R5.2, SW3.1
/SCL_3V3: Q2.2, R8.1, U1.6
/SCL_5V: J1.2, Q2.3, R3.1
/SDA_3V3: Q1.2, R7.1, U1.3
/SDA_5V: J1.1, Q1.3, R1.1
/~CHANGE: J1.3, R2.2, U1.5
GND: C1.2, C2.2, C3.1, C4.1, J1.4, U1.2, U1.14, U2.2
unnamed: R4.1, U1.11
unnamed: R5.1, U1.10
unnamed: R6.1, U1.12

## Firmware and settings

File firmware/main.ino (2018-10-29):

//******************************************************************************
//
// Project : Alarm Clock V3
// File    : main.ino
// Author  : Benoit Frigon <www.bfrigon.com>
//
// -----------------------------------------------------------------------------
//
// This work is licensed under the Creative Commons Attribution-ShareAlike 4.0
// International License. To view a copy of this license, visit
//
// http://creativcommons.org/licenses/by-sa/4.0/
//
// or send a letter to Creative Commons,
// PO Box 1866, Mountain View, CA 94042, USA.
//
//******************************************************************************


#include <Arduino.h>
#include <SD.h>
#include <Sodaq_DS3231.h>
#include <winc1500_async.h>
#include <SPI.h>
#include <Wire.h>
#include <avr/wdt.h>

#include "main.h"
#include "lamp.h"
#include "alarm.h"
#include "resources.h"
#include "screen.h"
#include "config.h"
#include "qt1070.h"
#include "us2066.h"
#include "neoclock.h"
#include "tpa2016.h"


Alarm g_alarm( PIN_VS1053_RESET, PIN_VS1053_CS, PIN_VS1053_XDCS, PIN_VS1053_DREQ, PIN_VS1053_SDCS, PIN_SD_DETECT, PIN_ALARM_SW );
TPA2016 g_amplifier( PIN_AMP_SHDN );
NeoClock g_clock( PIN_NEOCLOCK );
Lamp g_lamp( PIN_PIX_LAMP );
QT1070 g_keypad( PIN_INT_KEYPAD );
US2066 g_lcd( I2C_ADDR_OLED, PIN_OLED_RESET, PIN_OLED_VEN );

uint8_t test = 0;

bool g_clockUpdate = true;
uint8_t selectedProfile = 0;
uint8_t selectedAlarm = 0;
bool edit_alarm_lamp_settings = false;

volatile bool rtc_event = false;


struct Time adjTime;
struct Date adjDate;

Screen screen_root ( SCREEN_ID_ROOT, NULL, NULL, &enterScreen, &exitScreen );
Screen screen_main_menu( SCREEN_ID_MAIN_MENU, ITEMS_MAIN_MENU, eventValueChange, &enterScreen, &exitScreen );
Screen screen_display( SCREEN_ID_SETTINGS, ITEMS_DISPLAY_SETTINGS, &eventValueChange, &enterScreen, &exitScreen );
Screen screen_network( SCREEN_ID_NETWORK, ITEMS_NETWORK, NULL, &enterScreen, &exitScreen );
Screen screen_set_time( SCREEN_ID_SET_TIME, ITEMS_SET_TIME, &eventValueChange, &enterScreen, &exitScreen );
Screen screen_set_alarms( SCREEN_ID_SET_ALARMS, ITEMS_SET_ALARM, &eventValueChange, &enterScreen, &exitScreen );
Screen screen_edit_alarm( SCREEN_ID_EDIT_ALARM, ITEMS_EDIT_ALARM, &eventValueChange, &enterScreen, &exitScreen );
Screen screen_show_alarms( SCREEN_ID_SHOW_ALARMS, NULL, NULL, &enterScreen, &exitScreen );
Screen screen_edit_profile( SCREEN_ID_EDIT_PROFILE, ITEMS_EDIT_PROFILE, &eventValueChange, &enterScreen, &exitScreen );
Screen screen_list_profiles( SCREEN_ID_LIST_PROFILES, ITEMS_LIST_PROFILES, &eventValueChange, &enterScreen, &exitScreen );
Screen screen_edit_night_lamp( SCREEN_ID_EDIT_NIGHT_LAMP, ITEMS_EDIT_NIGHT_LAMP, &eventValueChange, &enterScreen, &exitScreen );
Screen screen_edit_alarm_lamp( SCREEN_ID_EDIT_ALARM_LAMP, ITEMS_EDIT_ALARM_LAMP, &eventValueChange, &enterScreen, &exitScreen );
Screen screen_edit_alarm_visual( SCREEN_ID_EDIT_ALARM_VISUAL, ITEMS_EDIT_PROFILE_VISUAL, &eventValueChange, &enterScreen, &exitScreen );

void initScreens() {

    /* Root screen */
    screen_root.eventDrawScreen = &root_eventDrawScreen;
    screen_root.eventKeypress = &root_eventKeypress;

    /* Set time screen */
    screen_set_time.confirmChanges = true;
    screen_set_time.eventSelectionChanged = &eventSelectionChange;

    /* Set alarm screen */
    screen_set_alarms.eventDrawItem = &eventDrawItem;

    /* Show alarms screen */
    screen_show_alarms.timeout = 3000;
    screen_show_alarms.eventKeypress = &show_alarm_eventKeypress;
    screen_show_alarms.eventDrawScreen = &show_alarm_eventDrawScreen;

    /* Network settings screen */
    screen_network.confirmChanges = true;

    /* List profile screen */
    screen_edit_profile.eventSelectionChanged = &eventSelectionChange;
    screen_edit_profile.eventDrawItem = &eventDrawItem;

    /* Edit alarm lamp settings */
    screen_edit_alarm_lamp.eventSelectionChanged = &eventSelectionChange;

    /* Edit night lamp settings */
    screen_edit_night_lamp.eventSelectionChanged = &eventSelectionChange;
    screen_edit_night_lamp.eventDrawItem = &eventDrawItem;

    /* Edit alarm lamp settings */
    screen_edit_alarm_visual.eventSelectionChanged = &eventSelectionChange;
}


void configWiFi() {

    IPAddress net_ip( &g_config.net_ip[0] );
    IPAddress net_mask( &g_config.net_mask[0] );
    IPAddress net_gateway( &g_config.net_gateway[0] );
    IPAddress net_dns( &g_config.net_dns[0] );

    WiFi.config( g_config.net_dhcp, net_ip, net_dns, net_gateway, net_mask );


}


void setup() {

    pinMode( PIN_PIX_SHDN, OUTPUT );
    digitalWrite( PIN_PIX_SHDN, LOW );

    /* Initialize clock display */
    g_clock.begin();

    g_lamp.begin();


    /* Check for factory reset sequence */
    if ( checkFactoryResetBtn() == false ) {

        /* Load configuration from EEPROM */
        loadConfig();
    }

    /* Set clock display color and brightness */
    g_clock.setColorFromTable( g_config.clock_color );
    g_clock.setBrightness( g_config.clock_brightness );
    g_clock.update();


    /* Enable watchdog timer, 4 seconds timeout */
    wdt_enable(WDTO_4S);

    /* Setup serial */
    Serial.begin( 115200 );


    /* Setup audio codec */
    g_alarm.begin();


    /* Initialize I2C Bus and DS3231 RTC */
    pinMode( PIN_INT_RTC, INPUT_PULLUP );
    attachInterrupt( digitalPinToInterrupt( PIN_INT_RTC ), isr_rtc, FALLING );

    rtc.begin();
    rtc.enableInterrupts(EveryMinute);

    rtc_event = true;   /* Force rtc event to update clock display */

    Wire.setClock(100000);


    /* Initialize OLED display */
    g_lcd.begin();
    g_lcd.setCustomCharacters( CUSTOM_CHARACTERS_ROOT );
    g_lcd.setContrast( g_config.lcd_contrast );


    initScreens();
    g_currentScreen = &screen_root;

    g_keypad.begin();

    /* Init wifi module */
    WiFi.setPins( PIN_WIFI_CS, PIN_WIFI_IRQ, PIN_WIFI_RESET, PIN_WIFI_ENABLE );
    WiFi.init(); 

    configWiFi();

    WiFi.connect( g_config.ssid, g_config.wkey );


    /* Configure audio amp */
    g_amplifier.begin();
    g_amplifier.setFixedGain( 25 );  
}




void loop() {



    /* Reset watchdog timer */
    wdt_reset();


    /* Process Keypad event if available */
    uint8_t key = g_keypad.processEvents();
    
    if ( key != KEY_NONE ) {

        g_currentScreen->processKeypadEvent( key );
    }

    /* Process RTC event if available */
    if ( rtc_event == true ) {
        
        rtc_event = false;
        rtc.clearINTStatus();

        DateTime now = rtc.now();

        if ( g_currentScreen->id == SCREEN_ID_ROOT ) {
            g_screenUpdate = true;
        }

        if ( g_currentScreen->id != SCREEN_ID_SET_TIME ) {

            g_clock.hour = now.hour();
            g_clock.minute = now.minute();

            g_clockUpdate = true;
        }

        g_alarm.checkForAlarms( &now );
    }


    /* Detect if the SD card is present, if so, initialize it */
    if ( g_alarm.isSDCardPresent() != g_alarm.DetectSDCard() ) {
        g_screenUpdate = true;
    }

    /* Detect alarm switch state */
    if ( g_alarm.isAlarmSwitchOn() != g_alarm.detectAlarmSwitchState()) {
        g_clockUpdate = true;
    }

    /* Feed alarm audio buffer and process visual effect */
    g_alarm.processAlarmEvents();


    /* Exit the current screen if it has reached its timeout value */
    if ( g_currentScreen->isTimeout() ) {

        if ( g_currentScreen->eventTimeout != NULL ) {
            g_currentScreen->eventTimeout( g_currentScreen );
            g_currentScreen->resetTimeout();

        } else {
            g_currentScreen->exitScreen();
        }
    }


    /* Update the current screen if requested */
    if ( g_screenUpdate == true ) {

        g_currentScreen->update();
        g_screenUpdate = false;
    }


    /* Update the Clock display if requested */
    g_clock.processUpdateEvents();

    /* Process lamp effect if lamp is active */
    g_lamp.processEvents();


    /* Handle pending WiFi module events */
    WiFi.handleEvents();

    if ( WiFi.statusChanged() == true ) {

        if ( g_currentScreen->id == SCREEN_ID_ROOT )  {
            g_screenUpdate = true;
        }
    }


    
}


//--------------------------------------------------------------------------
//
// Interrupts service
//
//--------------------------------------------------------------------------

void isr_rtc() {

    rtc_event = true;
}




bool checkFactoryResetBtn() {
    unsigned long start = millis();
    bool resetConfig = false;
    uint8_t i;

    while ( digitalRead ( PIN_FACTORY_RESET ) == LOW ) {


        /* Sets the config reset flag in eeprom after 1 seconds */
        if (( millis() - start ) > 1000 ) {

            g_clock.setColorFromTable( COLOR_RED );
            g_clock.setBrightness( 60 );
            g_clock.setTestMode( true );

            g_clock.status_set = true;
            g_clock.update();


            restoreDefaultConfig();

            for ( i = 0; i < 4; i++ ) {

                g_clock.status_set = ( i % 2 ) > 0;
                g_clock.update();
                delay( 200 );
            }

            resetConfig = true;
            break;
        }
    }

    g_clock.status_set = false;
    g_clock.setTestMode( false );
    g_clock.update();

    return resetConfig;
}


void resetClockDisplay() {

    DateTime now = rtc.now();

    g_clock.hour = now.hour();
    g_clock.minute = now.minute();
    g_clock.hourFlashing = false;
    g_clock.minutesFlashing = false;

    g_clock.status_set = false;

    g_clockUpdate = true;
}



//--------------------------------------------------------------------------
//
// Screen events
//
//--------------------------------------------------------------------------

bool eventDrawItem( Screen *screen, Item *item, bool isSelected, uint8_t row, uint8_t col ) {
    uint8_t length;

    switch ( item->id ) {
        case ID_PROFILE_FILENAME:

            g_lcd.print( isSelected ? CHAR_SELECT : CHAR_FIELD_BEGIN );

            if ( g_alarm.profile.filename[0] == 0x00 ) {
                length = g_lcd.print_P( S_PROFILE_DEF_FILENAME );
            } else {
                length = g_lcd.print( g_alarm.profile.filename );
            }

            g_lcd.fill ( CHAR_SPACE, item->length - length );
            g_lcd.print( isSelected ? CHAR_SELECT_REV : CHAR_FIELD_END );

            return false;

        case ID_ALARM_EDIT_1:
        case ID_ALARM_EDIT_2:
            uint8_t alarm_id;
            alarm_id = item->id - ID_ALARM_EDIT_1;

            Time time;
            g_alarm.readProfileAlarmTime( alarm_id , &time, NULL );

            char bufTime[9];
            length = timeToBuf( bufTime, g_config.clock_24h, &time);

            g_lcd.print( bufTime );
            if ( length < 8 ) {
                g_lcd.fill( CHAR_SPACE, 8 - length );
            }

            return false;

        case ID_LAMP_DELAY:
        case ID_PROFILE_SNOOZE:

            uint8_t minutes;
            minutes = *(( uint8_t* )item->value );

            if (minutes > 1 ) {
                length = g_lcd.printf_P( S_NEXT_ALARM_M, minutes);
            } else if (minutes == 1 ) {
                length = g_lcd.print_P( S_NEXT_ALARM_1MIN );

            } else {
                length = g_lcd.print_P( S_OFF );
            }
            g_lcd.fill( CHAR_SPACE, DISPLAY_WIDTH - length );


            return false;
    }

    return true;
}


void eventSelectionChange( Screen *screen, Item *item, uint8_t fieldPos, bool fullscreen ) {
    
    switch ( item->id ) {
        case ID_PROFILE_FILENAME:
        case ID_PROFILE_VOLUME:

            if ( fullscreen ) {
                g_alarm.play( ALARM_MODE_TEST_AUDIO, SELECT_FILE_PLAY_DELAY );
            } else {
                g_alarm.stop();
            }

            break;

        case ID_PROFILE_VISUAL_SPEED:
        case ID_PROFILE_VISUAL_MODE:

            if ( fullscreen ) {
                g_alarm.play( ALARM_MODE_TEST_VISUAL );
            } else {
                g_alarm.stop();
            }

            break;

        case ID_LAMP_MODE:
            if ( g_alarm.profile.lamp.mode == LAMP_MODE_OFF ) {
                g_lamp.deactivate();
                break;
            }

            /* Fall through */

        case ID_LAMP_EFFECT_SPEED:
        case ID_LAMP_COLOR:
        case ID_LAMP_BRIGHTNESS:

            NightLampSettings *settings;
            settings = edit_alarm_lamp_settings ? &g_alarm.profile.lamp : &g_config.lamp;
        
        
            if ( fullscreen ) {
                g_lamp.activate( settings, ( item->id != ID_LAMP_EFFECT_SPEED ));
            } else {
                g_lamp.deactivate();
            }
            break;

        


        case ID_SET_TIME:

            g_clock.hourFlashing = ( fieldPos == 0);
            g_clock.minutesFlashing = ( fieldPos == 1);

            g_clockUpdate = true;

            break;

        default:

            if ( g_clock.hourFlashing == true || g_clock.minutesFlashing == true ) {

                g_clock.hourFlashing = false;
                g_clock.minutesFlashing = false;

                g_clockUpdate = true;
            }

            break;

    }
}

bool eventValueChange( Screen *screen, Item *item ) {

    switch (item->id) {

        case ID_CLOCK_24H:

            g_clockUpdate = true;
            break;

        case ID_CLOCK_COLOR:
            g_clock.setColorFromTable( g_config.clock_color );

            g_clockUpdate = true;
            break;

        case ID_CLOCK_BRIGHTNESS:
            g_clock.setBrightness( g_config.clock_brightness );

            g_clockUpdate = true;
            break;

        case ID_LCD_CONTRAST:
            g_lcd.setContrast( g_config.lcd_contrast );
            break;


        case ID_PROFILE_FILENAME:
            g_alarm.openNextFile();
            g_alarm.play( ALARM_MODE_TEST_AUDIO, SELECT_FILE_PLAY_DELAY );

            break;

        case ID_SET_DATE_DAY:
        case ID_SET_DATE_YEAR:
        case ID_SET_DATE_MONTH:

            uint8_t month_days;
            month_days = getMonthNumDays( adjDate.month, adjDate.year );

            if ( adjDate.day > month_days ) {

                if ( item->id == ID_SET_DATE_DAY) {
                    adjDate.day = 1;
                } else {
                    adjDate.day = month_days;
                }
            }
            break;            

        case ID_PROFILE_VOLUME:
            g_alarm.setVolume( g_alarm.profile.volume );

            if ( g_alarm.isPlaying() == false ) {
                
                g_alarm.play( ALARM_MODE_TEST_AUDIO, SELECT_FILE_PLAY_DELAY );
            }

            break;


        case ID_PROFILE_TEST:
            g_alarm.play( ALARM_MODE_TEST_PROFILE );
            break;

        
        case ID_PROFILE_VISUAL_MODE:
            g_alarm.play( ALARM_MODE_TEST_VISUAL );
            break;

        case ID_ALARM_ON_1:
        case ID_ALARM_ON_2:
            g_clockUpdate = true;
            break;

        case ID_ALARM_EDIT_1:
        case ID_ALARM_EDIT_2:
            selectedProfile = item->id - ID_ALARM_EDIT_1;

            g_alarm.loadProfile( selectedProfile );
            break;

        case ID_SET_TIME:
            g_clock.hour = adjTime.hour;
            g_clock.minute = adjTime.minute;
            
            g_clockUpdate = true;
            break;

        case ID_LAMP_DELAY:
        case ID_PROFILE_SNOOZE:
            uint8_t minutes;
            minutes = *(( uint8_t* )item->value );

            if ( minutes > 10 ) {
                minutes = ( minutes % 5 ) ? (( minutes / 5 ) * 5 ) + 5  : minutes;
            }

            if ( minutes > 30 ) {
                minutes = ( minutes % 10 ) ? (( minutes / 10 ) * 10 ) + 10  : minutes;
            }

            *(( uint8_t* )item->value ) = minutes;
            break;


        case ID_LAMP_MODE:
            if (( uint8_t* )item->value == LAMP_MODE_OFF ) {
                g_lamp.deactivate();
            } else {
                g_lamp.activate( edit_alarm_lamp_settings == true ? &g_alarm.profile.lamp : &g_config.lamp );
            }
            break;

        case ID_LAMP_COLOR:
            g_lamp.setColorFromTable( *(( uint8_t* )item->value ));
            break;

        case ID_LAMP_BRIGHTNESS:
            g_lamp.setBrightness( *(( uint8_t* )item->value ));
            break;

        case ID_LAMP_EFFECT_SPEED:
            g_lamp.setEffectSpeed( *(( uint8_t* )item->value ));
            break;
    }

    return true;
}


bool enterScreen( Screen *screen ) {

    DateTime now;

    switch ( screen->id ) {

        case SCREEN_ID_SET_TIME:
            now = rtc.now();

            adjTime.hour = now.hour();
            adjTime.minute = now.minute();
            adjDate.day = now.date();
            adjDate.month = now.month();
            adjDate.year = (uint8_t)( now.year() - 2000 );

            g_clock.status_set = true;
            g_clockUpdate = true;

            break;

        case SCREEN_ID_SHOW_ALARMS:

            now = rtc.now();

            int8_t alarm_id;
            alarm_id = g_alarm.getNextAlarmID( &now, false );

            Time time;
            g_alarm.readProfileAlarmTime( alarm_id, &time, NULL );

            if ( alarm_id != -1 ) {

                g_clock.hour = time.hour;
                g_clock.minute = time.minute;

                g_clockUpdate = true;
            }

        case SCREEN_ID_EDIT_ALARM_LAMP:
            edit_alarm_lamp_settings = true;
            break;

        case SCREEN_ID_EDIT_NIGHT_LAMP:
            edit_alarm_lamp_settings = false;
            break;

        case SCREEN_ID_ROOT:
            g_lcd.setCustomCharacters( CUSTOM_CHARACTERS_ROOT );
            break;

        

    }

    return true;
}

bool exitScreen( Screen *currentScreen, Screen *newScreen ) {

    bool save;
    if ( currentScreen->confirmChanges == true ) {
        save = ( currentScreen->returnValue == RETURN_YES );
    } else {

        save = currentScreen->itemChanged;
    }



    switch ( currentScreen->id ) {

        case SCREEN_ID_SET_TIME:

            

            if ( save == true ) {

                uint8_t dow;
                dow = getDayOfWeek( adjDate.year, adjDate.month, adjDate.day );
                

                DateTime nDate( 2000 + adjDate.year,
                                adjDate.month,
                                adjDate.day,
                                adjTime.hour,
                                adjTime.minute,
                                0,
                                dow );

                /* Update the RTC */
                rtc.setDateTime( nDate );
            }

            resetClockDisplay();
            break;

        case SCREEN_ID_NETWORK:
            if ( save == true ) {
                saveConfig();

                configWiFi();

            } else {
                loadConfig();
            }
            break;

        case SCREEN_ID_EDIT_NIGHT_LAMP:
            if ( save == true ) {
                saveConfig();
            } else {
                loadConfig();
            }

            g_lamp.deactivate();
            break;

        case SCREEN_ID_EDIT_ALARM_LAMP:
        case SCREEN_ID_EDIT_ALARM:
        case SCREEN_ID_EDIT_PROFILE:
            if ( save == true ) {
                g_alarm.saveProfile( &g_alarm.profile, selectedProfile );
            }

            break;

        case SCREEN_ID_SET_ALARMS:
            ( save == true ) ? saveConfig() : loadConfig();

            g_clockUpdate = true;

            break;

        case SCREEN_ID_SHOW_ALARMS:
            resetClockDisplay();
            break;

        case SCREEN_ID_SETTINGS:
            if ( save == true ) {
                saveConfig();
            }
            break;

        case SCREEN_ID_ROOT:
            g_lamp.deactivate();

            g_lcd.setCustomCharacters( CUSTOM_CHARACTERS_MENUS );
            break;
    }

    return true;
}




//--------------------------------------------------------------------------
//
// Root screen events
//
//--------------------------------------------------------------------------

bool root_eventKeypress( Screen *screen, uint8_t key ) {

    switch (key) {
        case KEY_MENU:
            gotoScreen( &screen_main_menu, true, &screen_root );
            break;

        case KEY_SET | KEY_SHIFT:
            gotoScreen( &screen_set_time, true, &screen_root );
            break;

        case KEY_ALARM | KEY_SHIFT:
            gotoScreen( &screen_set_alarms, true, &screen_root );
            break;

        case KEY_ALARM:
            gotoScreen( &screen_show_alarms, true, &screen_root );
            break;

        case KEY_SWIPE | KEY_RIGHT:
            g_config.lamp.mode = LAMP_MODE_ON;
            g_lamp.activate( &g_config.lamp );
            break;

        case KEY_SWIPE | KEY_LEFT:
            g_lamp.deactivate();
            break;

        case KEY_SET:
            /* temporary */
            g_alarm.loadProfile( 0 );
            g_alarm.play( ALARM_MODE_NORMAL );

            break;
    }

    return false;
}

bool root_eventDrawScreen( Screen *screen ) {

    char buffer[16];
    DateTime now = rtc.now();


    /* Print status icons */
    g_lcd.setPosition(0, 13);

    g_lcd.print(( g_alarm.isSnoozing() == true ) ? CHAR_ALARM : CHAR_SPACE);
    g_lcd.print(( WiFi.connected() == true) ? CHAR_WIFI_ON : CHAR_SPACE );
    g_lcd.print(( g_alarm.isSDCardPresent() == false ) ? CHAR_NO_SD : CHAR_SPACE);


    /* Print date */
    dateToBuf( buffer, g_config.date_format, &now );

    g_lcd.setPosition(1, 0);
    uint8_t length = g_lcd.print( buffer );
    g_lcd.fill( CHAR_SPACE, DISPLAY_WIDTH - length );

    return false;
}



//--------------------------------------------------------------------------
//
// Show next alarm screen events
//
//--------------------------------------------------------------------------
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

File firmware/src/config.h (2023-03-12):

//******************************************************************************
//
// Project : Alarm Clock V3
// File    : config.h
// Author  : Benoit Frigon <www.bfrigon.com>
//
// -----------------------------------------------------------------------------
//
// This work is licensed under the Creative Commons Attribution-ShareAlike 4.0
// International License. To view a copy of this license, visit
//
// http://creativecommons.org/licenses/by-sa/4.0/
//
// or send a letter to Creative Commons,
// PO Box 1866, Mountain View, CA 94042, USA.
//
//******************************************************************************
#ifndef CONFIG_H
#define CONFIG_H

#include <Arduino.h>
#include <EEPROM.h>
#include <SdFat.h>
#include <avr/pgmspace.h>
#include <IPAddress.h>
#include <time.h>
#include <itask.h>
#include <resources.h>


#define IPADDRESS_TO_ARRAY( src, dest )   dest[ 0 ] = src[ 0 ]; \
                                          dest[ 1 ] = src[ 1 ]; \
                                          dest[ 2 ] = src[ 2 ]; \
                                          dest[ 3 ] = src[ 3 ]; 

#define BATTERY_DESIGN_CAPACITY         350


#define CONFIG_BACKUP_FILENAME          "config.txt"


/* Limits */
#define MAX_LENGTH_SETTING_NAME         32
#define MAX_LENGTH_SETTING_VALUE        96
#define MAX_NUM_PROFILES                2
#define MAX_LENGTH_ALARM_FILENAME       64
#define MAX_LENGTH_ALARM_MESSAGE        16
#define MAX_SSID_LENGTH                 32
#define MAX_HOSTNAME_LENGTH             32
#define MAX_NTPSERVER_LENGTH            64
#define MAX_WKEY_LENGTH                 63
#define MIN_CLOCK_BRIGHTNESS            10
#define MAX_CLOCK_BRIGHTNESS            80
#define MIN_LAMP_BRIGHTNESS             5
#define MAX_LAMP_BRIGHTNESS             100
#define MIN_LAMP_DELAY_OFF              0
#define MAX_LAMP_DELAY_OFF              90
#define MIN_LCD_CONTRAST                0
#define MAX_LCD_CONTRAST                100
#define MIN_ALARM_LAMP_BRIGHTNESS       25
#define MAX_ALARM_LAMP_BRIGHTNESS       100
#define MIN_ALARM_LAMP_EFFECT_SPEED     1
#define MAX_ALARM_LAMP_EFFECT_SPEED     10
#define MIN_ALARM_SNOOZE_TIME           0
#define MAX_ALARM_SNOOZE_TIME           30
#define MIN_ALARM_VOLUME                20
#define MAX_ALARM_VOLUME                100
#define MIN_ALARM_VISUAL_EFFECT_SPEED   1
#define MAX_ALARM_VISUAL_EFFECT_SPEED   10
#define MAX_TZ_NAME_LENGTH              40
#define MAX_MQTT_HOST_LENGTH            64
#define MAX_MQTT_USERNAME_LENGTH        32
#define MAX_MQTT_PASSWORD_LENGTH        32
#define MAX_DISCOVERY_PREFIX_LENGTH     32
#define MAX_FTP_USERNAME_LENGTH         32
#define MAX_FTP_PASSWORD_LENGTH         32

/* EEPROM addresses */
#define EEPROM_ADDR_MAGIC               0
#define EEPROM_ADDR_FIRMWARE_VER        4
#define EEPROM_ADDR_CLOCK_CONFIG        10
#define EEPROM_ADDR_NETWORK_CONFIG      EEPROM_ADDR_CLOCK_CONFIG + ( sizeof( ClockSettings ) )
#define EEPROM_ADDR_PROFILES            EEPROM_ADDR_NETWORK_CONFIG + ( sizeof( NetworkSettings ) )

/* EEPROM settings sections */
#define EEPROM_SECTION_CLOCK            0x01
#define EEPROM_SECTION_NETWORK          0x02
#define EEPROM_SECTION_ALL              EEPROM_SECTION_CLOCK | EEPROM_SECTION_NETWORK

/* Settings type */
enum {
    SETTING_TYPE_UNKNOWN = 0,
    SETTING_TYPE_BOOL,
    SETTING_TYPE_STRING,
    SETTING_TYPE_SECTION,
    SETTING_TYPE_INTEGER,
    SETTING_TYPE_IP,
    SETTING_TYPE_COMMENT,
    SETTING_TYPE_TIME,
    SETTING_TYPE_DOW,
    SETTING_TYPE_SHORT,
    SETTING_TYPE_TIMEZONE,
};

#define SETTING_VALUE_FALSE                 "off"
#define SETTING_VALUE_TRUE                  "on"


PROG_STR( COMMENT_FILE_HEADER,              "; -----------------------\r\n"
                                            "; Alarm clock V3 settings\r\n"
                                            "; -----------------------\r\n" );
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

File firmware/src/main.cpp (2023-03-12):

//******************************************************************************
//
// Project : Alarm Clock V3
// File    : main.cpp
// Author  : Benoit Frigon <www.bfrigon.com>
//
// -----------------------------------------------------------------------------
//
// This work is licensed under the Creative Commons Attribution-ShareAlike 4.0
// International License. To view a copy of this license, visit
//
// http://creativcommons.org/licenses/by-sa/4.0/
//
// or send a letter to Creative Commons,
// PO Box 1866, Mountain View, CA 94042, USA.
//
//******************************************************************************

#include <hardware.h>
#include <config.h>
#include <freemem.h>
#include "services/console.h"
#include "services/telnet_console.h"
#include "services/ntpclient.h"
#include "services/mqtt.h"
#include "services/homeassistant.h"
#include "services/logger.h"
#include "services/ftpserver.h"
#include "ui/ui.h"


SDCardManager   g_sdcard( PIN_SD_DETECT, PIN_VS1053_SDCS );
Alarm           g_alarm( PIN_VS1053_RESET, PIN_VS1053_CS, PIN_VS1053_XDCS, PIN_VS1053_DREQ,
                         PIN_ALARM_SW, PIN_AMP_SHDN, &g_sdcard );
WiFi            g_wifi( PIN_WIFI_CS, PIN_WIFI_IRQ, PIN_WIFI_RESET, PIN_WIFI_ENABLE );
NeoClock        g_clock( PIN_NEOCLOCK, PIN_PIX_SHDN );
Lamp            g_lamp( PIN_PIX_LAMP );
QT1070          g_keypad( PIN_INT_KEYPAD );
US2066          g_lcd( I2C_ADDR_OLED, PIN_OLED_RESET );
Power           g_power( PIN_ON_BATTERY, PIN_SYSOFF, PIN_FACTORY_RESET );
DS3231          g_rtc( PIN_INT_RTC );
ALS             g_als;
BQ27441         g_battery;
ConfigManager   g_config;
Console         g_console;
TelnetConsole   g_telnetConsole;
TimeZone        g_timezone;
NtpClient       g_ntp;
Screen          g_screen;
Logger          g_log;
MqttClient      g_mqtt;
HomeAssistant   g_homeassistant;
FTPServer       g_ftpServer( &g_sdcard );

bool g_prev_state_wifi = false;
bool g_prev_state_telnetConsole = false;
bool g_prev_sd_card_present = false;


/*******************************************************************************
 *
 * @brief   Checks if the check button is held after reset or if EEPROM 
 *          contains an invalid magic code. In that case, all settings are 
 *          restored to default.
 *
 * @return  TRUE if settings were reset to default, FALSE otherwise.
 * 
 */
bool checkFactoryReset() {

    /* No need to reset settings */
    if( g_config.isEepromValid() == true && g_power.detectConfigResetButton() == false ) {
        return false;
    }

    if( g_power.detectConfigResetButton() == true ) {

        unsigned long start = millis();

        /* Wait 1 second to test if the config reset continues to be pressed */
        while( g_power.detectConfigResetButton() == true ) {

            if( ( millis() - start ) >= 1000 ) {

                wdt_reset();
                break;
            }
        }

        /* Config reset button was released before the timeout.
        No need to reset settings */
        if( g_power.detectConfigResetButton() == false ) {
            return false;
        }
    }


    /* Set the clock display to "88:88" */
    g_clock.begin();
    g_clock.setColorFromTable( COLOR_RED );
    g_clock.setBrightness( 50 );
    g_clock.setTestMode( true );
    g_clock.update();

    /* Reset EEPROM to default values */
    g_config.reset();
    delay( 1000 );

    g_clock.restoreClockDisplay();

    return true;
}


/*******************************************************************************
 *
 * @brief   Initialize drivers
 *
 */
void setup() {
    
    g_log.add( EVENT_RESET, MCUSR );
    MCUSR = 0;

    /* Enable watchdog timer */
    g_power.enableWatchdog();

    /* Setup console */
    g_console.begin( 115200 );
    g_console.clearScreen();
    g_console.println_P( S_CONSOLE_INIT );

    /* Setup I2C */
    Wire.begin();
    Wire.setClock( 100000 );

    /* Initialize power management driver */
    g_power.begin();
    g_battery.begin( BATTERY_DESIGN_CAPACITY );

    /* Initialize ambiant light detector */
    g_als.begin();

    /* Check for factory reset sequence */
    if( checkFactoryReset() == false ) {

        /* Load configuration from EEPROM */
        g_config.load();
    }

    /* Initialize time zone */
    g_timezone.setTimezoneByName( g_config.clock.timezone );

    /* Initialize clock display */
    g_clock.begin();
    g_lamp.begin();

    /* Set clock display color and brightness */
    g_clock.setColorFromTable( g_config.clock.clock_color );
    g_clock.setBrightness( g_config.clock.clock_brightness );
    g_clock.update();

    /* Initialize DS3231 RTC */
    g_rtc.begin();
    g_rtc.setAlarmFrequency( RTC_ALARM_EVERY_SECOND );
    g_rtc.enableInterrupt();
    g_clock.restoreClockDisplay();

    /* Initialize OLED display */
    g_lcd.begin();
    g_lcd.setContrast( g_config.clock.lcd_contrast );

    /* Initialize touch keypad */
    g_keypad.begin();

    /* Initialize audio system */
    g_alarm.begin();

    /* Initialize WIFI driver */
    g_wifi.begin();
    g_wifi.setSystemTime( g_rtc.now() );
    delay( 250 );

    /* Initialize UI */
    g_screen.activate( &screen_root );

    /* Display console prompt */
    g_console.resetConsole();

    /* Start telnet server if enabled */
    g_telnetConsole.enableServer( g_config.network.telnetEnabled );

    /* Start FTP server if enabled */
    g_ftpServer.enableServer( g_config.network.ftp_enabled );

    /* Connect to the mqtt broker if enabled */
    g_mqtt.begin();
    g_mqtt.setPublishReceiveCallback( handleHassTopicCallback );

    /* Enable home assistant client via MQTT */
    g_homeassistant.begin();

    /* Enable automatic ntp sync at random interval */
    g_ntp.setAutoSync( g_config.clock.use_ntp );
}
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

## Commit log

2016-06-23 Updated mechanical drawings, display panel. Rev B
    [display panel - frame.stl, touch.kicad_pcb]
2016-06-26 Updated drawings - Display panel
    [display panel - frame.stl, touch.kicad_pcb]
2016-06-26 Changed display panel STL object orientation
    [display panel - frame.stl]
2016-07-03 Modified display panel frame, touch panel pcb
    [display panel - frame.stl, touch.kicad_pcb]
2016-07-05 Updated laser cut parts svg
2016-07-05 Changed symbolic links to hard links for schematics pdf
2016-07-11 * Fix wrong footprint for resistors (C-* to R-*) * Changed schematic sheet size to US letter
    [touch.kicad_pcb, touch.sch]
2016-07-11 Added gerber and pdf files of each layers for the touch PCB
    [touch.gbl, touch.gbo, touch.gbs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]
2016-07-11 * Changed sheet size to US Letter * Added gerber and pdf files of each layers
    [rgb-dots.kicad_pcb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]
2016-07-11 Remove mirror option for bottom layers
    [rgb-dots.kicad_pcb]
2016-07-11 Updated schematic of rgb-digits pcb * Changed sheet size to US letter * Added gerber and pdf files of each layers
    [rgb-digit.kicad_pcb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]
2016-07-11 Added schematic for front panel pcb
    [front-panel.kicad_pcb, front-panel.sch]
2016-07-11 Updated speaker holder stl file
    [speaker holder.stl]
2016-07-11 Changed sheet size to US letter
    [front-panel.sch]
2016-07-14 Added front panel pcb
    [front-panel.kicad_pcb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]
2016-07-14 Modified daughterboard board layout
    [daughterboard.kicad_pcb, daughterboard.sch, soundcard.sch]
2016-07-14 Added pictures of display frame
2016-07-15 Added light sensor pcb
    [light-sensor.kicad_pcb, light-sensor.sch]
2016-07-15 Added gerber files for light sensor pcb
    [light-sensor.gbl, light-sensor.gbo, light-sensor.gbs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]
2016-07-16 EN of 12V suply controlled from MCU instead of LCD GPIO
    [front-panel.kicad_pcb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]
2016-07-16 Added No connect symbol for GPIO pin on LCD module
    [front-panel.sch]
2016-07-21 Removed 3.3v regulator and level shifters
    [light-sensor.kicad_pcb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]
2016-07-21 Changed touch keypad, front panel and light sensor pcb to a two layer design.
    [front-panel.kicad_pcb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]
2016-07-21 Added panelized pcbs - display
    [panel-display.kicad_pcb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]
2016-07-21 Updated system overview diagram to include the interrupt signal of the light sensor.
2016-07-22 Centered the light sensor horizontally
    [light-sensor.kicad_pcb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]
2016-07-22 Added pull down resistor to Reset line.
    [front-panel.kicad_pcb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]
2016-07-22 Updated display pcb panel
    [panel-display.kicad_pcb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]
2016-07-22 Deleted unneeded gerber files for layer 2 and 3 (gl2,gl3)
2018-08-22 Revised touch and front panel PCB, Added Motherboard PCB
    [alarm-switch.kicad_pcb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]
2018-08-24 Changed DC jack position on motherboard
    [motherboard.drl, motherboard.gbl, motherboard.gbo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]
2018-08-27 Updated fab files
    [back panel.stl, base - lower section.stl, base - upper section.stl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]
2018-08-27 Changed print direction for back panel
    [back panel.stl]
2018-08-28 Adjusted page size for motherboard schematic
    [motherboard.kicad_pcb, motherboard.sch, peripherals.sch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]
2018-08-28 Added STL file for pcb assembly jig
    [jig-assy-motherboard.stl]
2018-08-29 Replaced RGB leds with IN-PI554FCH instead of WS2812B
    [rgb-digit.sch, rgb-dots.sch, rgb-lamp.sch]
2018-09-19 Updated PCB design
    + Completed daughterboard PCB layout.
    * Corrected soldermask clerance on front panel pcb.
    - Removed input resistor on DIN for RGB lamp board.
    * Modified PCB layout for PSU board.
    * Updated gerber files.
    * Updated schematics pdf, BOM.
    [alarm-switch.kicad_pcb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]
2018-09-20 Changed cap C13 from 100nF to 1uF
    * Use 1uF on C13 to generate a longer reset pulse when pressing the cfg/reset button.
    [motherboard.sch]
2018-09-23 Replaced battery holder for Harwin S8411-45R
    [motherboard.drl, motherboard.gbl, motherboard.gbo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]
2018-09-24 Corrected bad description for part U9
    [motherboard.kicad_pcb]
2018-09-24 Fix: Wrong footprint for R20-22 and C14
    [motherboard.kicad_pcb, motherboard.sch, peripherals.sch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]
2018-10-29 Corrected solder mask clearance
    [_saved_psu.sch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]
2018-10-29 Updated schematic pdf
2018-10-29 Updated panel gerber files
    [daughterboard.drl, daughterboard.gbl, daughterboard.gbo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]
2018-10-29 Renamed schematic files
2018-10-29 Updated enclosure base stl files
2018-11-09 Changed pin for VUSB detection on U3
    [motherboard.drl, motherboard.gbl, motherboard.gbo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]
2018-11-16 Switched to SdFat library, re-organized directory structure
    [display-current-calc.ods]
2018-11-18 Fix: Events callback set on wrong screen
    [firmware.ino, us2066.cpp, wifi.cpp]
2018-11-22 Implemented backup/restore config from SD card, other changes
    + Moved config related global function to new ConfigManager class
    + Added Backup/restore config to SD card functionality.
    + Reset to factory defaults from menu.
    + Power management : Added control pin SYSOFF
    + Base class for task management
    * Code cleanup
    [alarm.cpp, alarm.h, config.h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]
2018-11-22 Added runTask() to Alarm, Power and Neoclock
    * Checks for alarms, alarm sw changes inside Alarm::runtask()
    * Checks for keypad event and screen timeout inside Screen::runtask()
    * rtc : minute,hour,etc. values are accessible directly
    * FIX: If alarm switch state changes, only update screen in suspend mode
    [alarm.cpp, alarm.h, firmware.ino]
2018-11-25 Added battery holder model
    [battery-holder.stl]
2018-11-28 PSU board schematics/layout
    [motherboard.kicad_pcb, motherboard.sch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]
2018-12-13 Added battery status screen
2018-12-13 Changed VUSB-DET pin on USB-serial IC from 18 to 22
    [_saved_psu.sch, psu.sch]
2018-12-31 Added final assembly pictures
2019-01-07 Bug fix: Read QT1070 interrupt pin level instead of relying on a flag
    Reads the interrupt pin level in the ProcessEvent routine to detect a
    key event instead of using an interrupt flag variable set in the ISR.
    This resolve occasional glitches where the keypad became unresponsive
    if the flag was cleared while an interrupt condition still existed.
    Since the QT1070 will hold the interrupt pin low as long as the data
    is not read, the interrupt is never raised again so the flag remains
    cleared and all subsequent key presses are ignored.
    [qt1070.cpp]
2019-01-07 Battery gauge status: Display true battery capacity and SOC (unfiltered)
2020-08-24 Night lamp enable/disable available on all menus
    + Added driver for TSL2591
    * Fix Syntax for optional arguments
    [alarm.cpp, alarm.h, firmware.ino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]
2020-12-21 Added serial console
    + Added ping capability to WiFi manager
    * Combined print functions common to console and LCD in the IPrint class
2020-12-29 Implemented time zones and daylight saving time
    - Removed swipe gestures as it cause key detection reliability issues
    * Hide input on console when entering WiFi password
    [alarm.cpp, config.h, console.cpp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]
2021-01-03 Added script to download and parse the IANA timezone database
    + Added printTimeInterval function to print interface
    * Store timezone in eeprom by name instead of the TZ table index
2021-01-05 Removed kicad project files from .gitignore
2021-01-15 Fix tabulation in Doxygen tags
    [wifi.cpp]
2021-01-24 Added printfln and printfln_P functions
2021-02-03 FIX: default ntp setting in 'set date' command
    'use ntp' default option not reflecting current value in config and
    always select no by default
2021-03-15 Fix: Incorrect daylight saving transition rules
    [main.cpp]
2021-07-12 Added battery status command to console
2023-01-24 Added MQTT/Home assistant support
    Publish alarm switch state changes, next alarm and
    WiFi RSSI to home assistant via a MQTT broker.
    [alarm.cpp, config.h]
2023-01-30 Exposes battery status to Home Assistant
2023-01-31 Fix: Mqtt auto-reconnect when connection lost
    [resources.h]
2023-02-05 Fix: Wait until WiFi is connected to sync clock
    * Don't attempt to auto-reconnect to MQTT broker
    while WiFi is busy processing another request.
    + Show ntp sync event in logs if +/- 10 seconds.
    [resources.h]
2023-02-06 Fix: First NTP sync at boot fail if WiFi is busy
    [resources.h]
2023-02-16 Added text sensor for displaying messages on the LCD from Home Assistant
2023-08-02 Removed duplicate device name from entities
